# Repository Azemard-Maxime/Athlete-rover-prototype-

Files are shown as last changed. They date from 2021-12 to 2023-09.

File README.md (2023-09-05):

# Athlete-rover-prototype-
Projet Arduino PeiP2: 
Lunar rover prototype

Création d'un robot capable de se déplacer et de grimper sur des obstacles. Inspiré par le rover lunaire Athlete. (L'objectif étant de simuler son comportement)

Creation of a robot which can move and climb on obstacles. Idea inspired by lunar rover Ahtlete.(Objective: simulation of the movement of a rover on uneven reliefs)

168147main_image_feature_748_ys_full

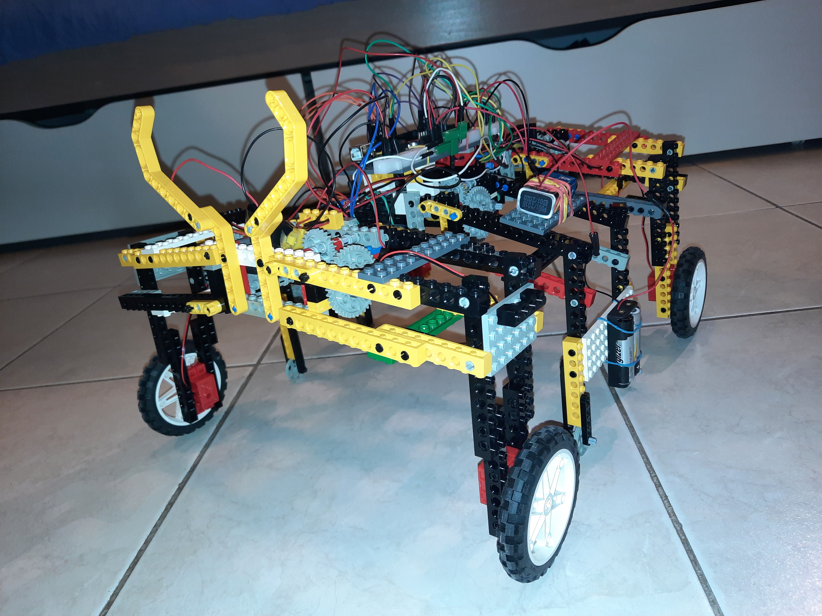
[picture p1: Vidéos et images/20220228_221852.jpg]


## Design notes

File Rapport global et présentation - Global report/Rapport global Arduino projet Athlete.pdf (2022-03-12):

# Athlete-rover-prototype-

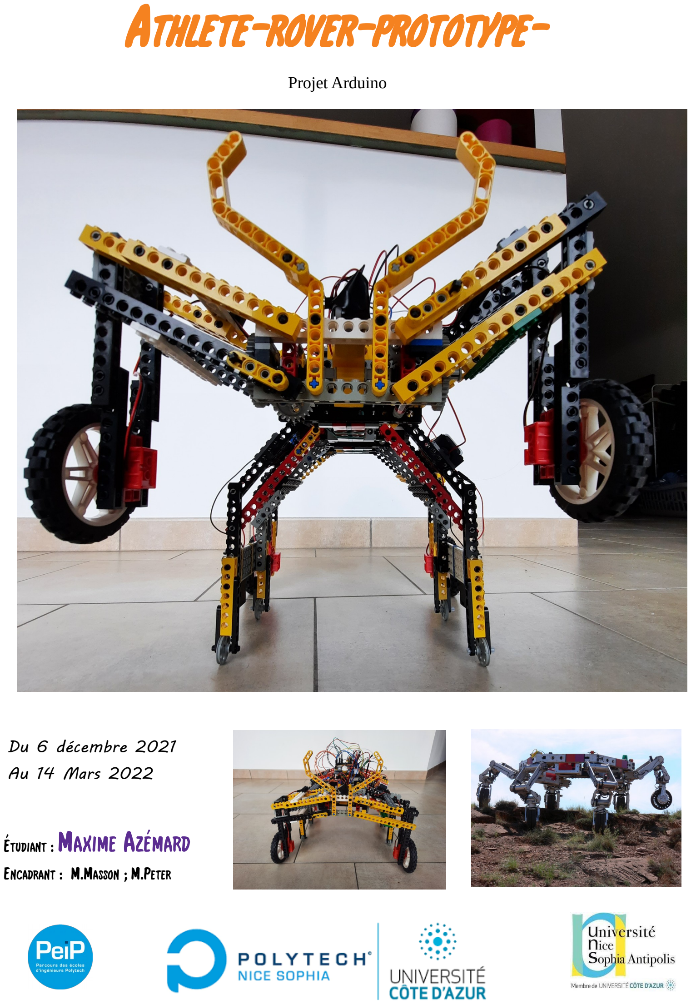
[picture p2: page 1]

Projet Arduino

# Étudiant : Maxime Azémard

### Encadrant : M.Masson ; M.Peter

### Du 6 décembre 2021 Au 14 Mars 2022

### Remerciements

L’équipe de création du prototype de rover Athlete remercie particulièrement M.Masson et son équipe pour leur implication, leur suivi et leurs conseils avisés. Nous remercions M.Juan pour la prise en charge efficace de l’impression des pièces nécessaires, et nous remercions l’université Côte d’Azur et l’école polytechnique universitaire de l’académie de Nice pour avoir permis l’accès au matériel et au outils de conception utiles à la réussite du projet.

Sommaire

Introduction Objectif réalisation
Contraintes (cahier des charges – planning initial – final Le matériel

Partie 1 : Le prototype initial
Partie 2 : Un robot plus modeste
Partie 3 : Un robot Athlète
Conclusion – Perspectives d’évolutions Bibliographie

## Projet Athlète : « A l’assaut du relief »

Depuis quelques années, la conquête spatiale s’accélère considérablement. Les agences spatiales du monde entier (la NASA, l’ESA, Roscosmos, ect) se préparent à un retour imminent et prolongé sur l’astre lunaire, et les envois de sondes et rovers à but scientifique s’intensifient avec l’objectif de voir, dans un futur proche, le premier être humain sur Mars.
Ces rovers, à l’image de Curiosity, parcourent des kilomètres afin d’étudier les minéraux et les sols extraterrestres. Ils se retrouvent ainsi face à un défi de grande envergure : le relief. Celui ci se dresse tel un obstacle destiné à freiner leurs progressions. Pour les ingénieurs actuels, la création d’un robot capable de se déplacer aisément sur ce relief représente l’un des principaux enjeux de la conquête spatiale à venir.
C’est dans l’objectif de répondre à cette difficulté que la NASA et le Jet Propulsion Laboratory développent en ce moment même le rover Athlete (All-Terrain Hex-Limbed Extra-Terrestrial Explorer ). Ce rover est composé de 6 trains de roues articulés qui s’adaptent au niveau du sol afin que la plateforme du robot reste stable de façon permanente. A l’avenir, l’agence spatiale américaine prévoit de l’envoyer sur la Lune à des fins de transports de marchandises, ou de modules d’habitats pour les futurs arrivants.
L’objectif de ce projet est de comprendre, par l’intermédiaire de la création d’un robot articulé et motorisé, comment se comporte le rover Athlete et de quelle façon il capable de franchir une différence de relief.
Au cours de ce rapport, après vous avoir présentez le premier prototype initial du robot, nous discuterons de la version simplifiée créée en milieu de projet avant de nous attacher à la présentation du robot finalisé à l’effigie de Athlete.

### Sommaire

Introduction | p.2
Cahier des charges – objectif de réalisations et contraintes | p.3
Le matériel | p.3
Partie 1 : Le prototype initial | p.4
Partie 2 : Un robot plus modeste | p.6
Partie 3 : Un robot Athlète | p.7
Conclusion – Perspectives d’évolutions | p.9
Bibliographie | p.10

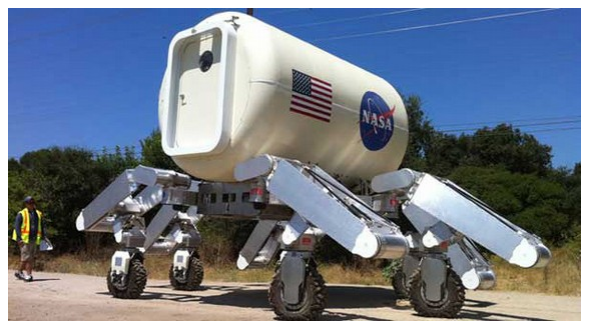
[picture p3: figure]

Photographie deAthlete
transportant un module
d’habitation

### Cahier des charges

Objectif : création d’un robot capable de réaliser la montée et la descente d’un obstacle afin de simuler le comportement d’Athlete lors de son déplacement sur des reliefs escarpés. Le robot doit être manipulé à distance avec un système de télécommande.

Projet de réalisation : Créer un robot composé de 3 trains de roues qui s’élèvent et s’abaissent successivement afin de se hisser ou descendre d’un obstacle.

Contraintes de réalisation :

- le robot doit être équipé de 3 paires de roues au minimum pour la gestion du centre de gravité.
- les trains avants et arrières doivent posséder des roues motrices et des pneus adhérents au sol afin de pouvoir pousser ou tracter le robot lors des phases de montée et de descente.
- le robot doit pouvoir communiquer à distance avec une télécommande. Un système de transfert de données est donc nécessaire (Bluetooth, …)
- chaque train doit être capable de fonctionner indépendamment des autres. Mais aussi tous ensemble.
- Le poids et les matériaux utilisés doivent être pris en compte afin de permettre une meilleure gestion du centre de gravité.
- chaque train de roues doit être capable de s’abaisser et se relever. Son articulation nécessite une motorisation
- Le robot nécessite d’avoir avec lui une source d’énergie : pile,etc
- nécessité d’une quantité importante de moteurs et roues
- délais : 8 semaines

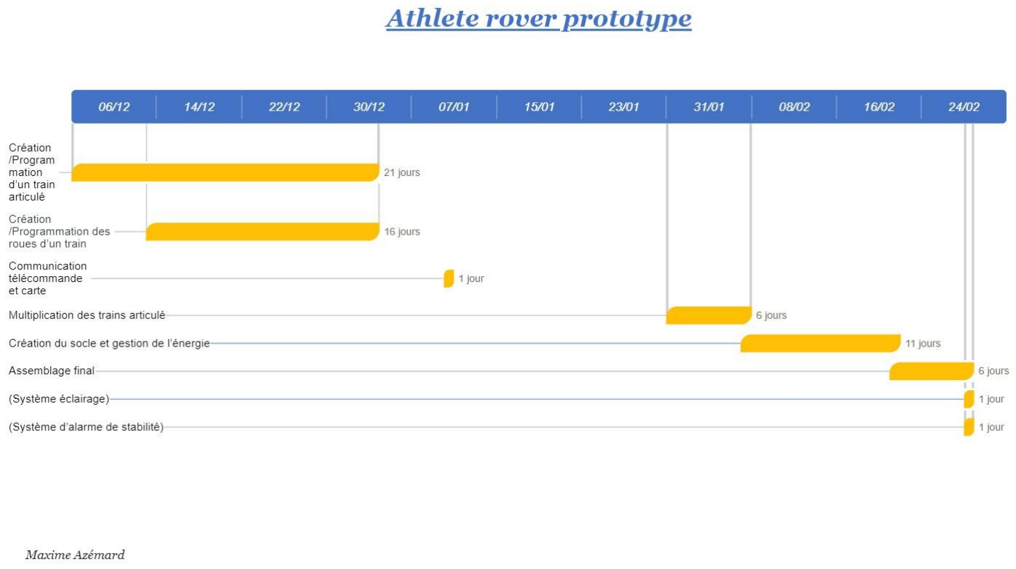
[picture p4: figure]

### Détails du matériels

Pour débuter, il est nécessaire de bien comprendre le matériel utilisé tout au long de ce projet. En voici quelques descriptions :

Planning initial du projet

- La carte Arduino UNO : Une carte programmable standard équipée d’un microcontroleur. Elle possède 14 entrées numériques dont 6 entrées « Pulse Width modulation » et 5 broches analogiques.
- La carte Arduino MEGA : Une carte programmable plus avancée que le modèle UNO. Utilisée pour des projet de plus grande envergure, elle possède 54 entrées/sorties dont 16 analogiques et 14 de type PWM.
- Les ponts en H : Un circuit permettant de contrôler deux moteurs à courant continu, ou un moteur pas à pas. Les ports ENA et ENB permettent de moduler la tension ce qui équivaut à moduler la vitesse des moteurs. Les entrées IN1, IN2, IN3 et IN4 permettent d’indiquer le sens de rotation des moteurs.
- Le module hc-05 : Un module qui fonctionne en Bluetooth et qui permet la communication entre la carte et un appareil externe. Fonctionne de pair avec l’application « Bluetooth electronic »
- Les moteurs Lego Geek : Des moteurs Lego à courant continu compatible avec Arduino
- Les moteurs « jaunes » : de simples moteurs à courant continu
- Les servomoteurs : des moteurs capables de prendre une position spécifique comprise dans un angle allant de 0° à 180°.

Partie 1 : Le prototype initial

L’objectif de cette première partie du projet est d’obtenir un premier prototype fonctionnel du robot. Il faut donc commencer par se poser certaines questions : Comment créer la structure de l’appareil ? Comment articuler les trains de roues et y insérer des moteurs ? Quels matériels utiliser ?

### I- La création du premier robot

De par la facilité d’utilisation, la brique Lego s’est avéré être plutôt adapté à ce projet. Après la création rapide d’un modèle de train pouvant être utilisé, la
structure du robot a pu être lancée. Celle-ci se décompose en 4
parties. Les trains avants et arrières qui se déploient vers
l’avant et qui sont composés chacun d’un moteur à courant continu compatible avec la structure Lego, qui contrôle l’articulation, et d’un autre moteur Lego qui permet la
motorisation des roues. Ce mouvement est possible grâce aux
vis sans fin qui maintiennent toutes la structure.

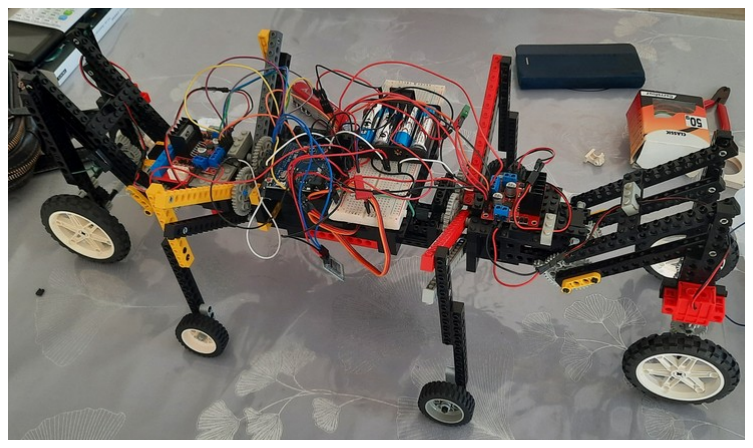
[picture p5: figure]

Les deux trains centraux sont équipés de servomoteurs. Par l’intermédiaire d’une pièce de jonction, ceux ci sont rattachés à des axes Legos qui sont eux-même reliés à des articulations à roulettes. Ici on remarque l’absence des vis sans fin.
L’électronique du robot nécessite l’utilisation de plusieurs modules. En ce début de projet, le choix de l’utilisation de la carte Arduino UNO a été fait afin de faire la liaison entre les commandes informatiques et l’électronique du robot. Ensuite, il a fallu s’équiper de 2 ponts en H qui servent d’intermédiaire entre la carte et les moteurs. Enfin un module de Bluetooth a été rajouté. Tous ces composants ont été ajoutés sur la structure mécanique Lego du robot et les branchements ont pu être effectués. Une platine d’essai s’est avérée indispensable pour permettre la bonne connexion de tous les modules. S’en est suivi l’introduction d’un bloc d’alimentation de 6V par piles et d’un interrupteur.
Enfin il a fallu programmer le prototype. Pour cela, un travail préparatoire a été nécessaire afin de créer des petits sous-programmes destinés aux tests des différents modules. A savoir, les

### Partie 1 : Le prototype initial

servomoteurs, les moteurs, et la connexion au module Bluetooth. Pour suivre, la télécommande a pu être créée et le premier programme écrit. L’idée ici est de permettre à l’utilisateur de manipuler tous les trains articulés ainsi que le déplacement de l’engin.

### II- Les problèmes rencontrés

Lors de la création de ce premier prototype de machine, plusieurs problèmes mécaniques se sont posés.
Premièrement, la question de l’insertion des moteurs Lego dans les parties avant et arrière ont été un problème. Pour le résoudre et obtenir la structure la moins coûteuse en pièces, il a fallu recréer et modifier plusieurs fois ces zones. Le but est ainsi d’avoir les trains les moins lourds possible.
Un autre problème de mécanique qui est apparu est la faible puissance des moteurs. Ils n’étaient pas capable de relever l’articulation. Pour cela l’utilisation d’engrenages est devenu indispensable. En effet il est possible grâce à eux de décupler la puissance exercé mais cela réduit considérablement la vitesse.
Pour suivre, il était devenu nécessaire de solidariser la structure. En effet les forces d’écartements qui s’exerçaient sur le robot fragilisaient énormément la structure de celui ci. Ce problème n’a pas pu être complètement résolu mais l’accrochage d’une grande barre Lego traversant tout l’appareil a permis de réduire considérablement cet effet de destruction.
On remarque un autre problème qui vient de la platine d’essai. On remarque qu’elle alourdi le robot alors qu’une grosse partie de la plaque n’est pas utilisée. Ce problème persistera une grande partie du projet. Il est aussi très délicat de trouver de la place pour insérer cette platine dans la structure.
Concernant la programmation, il a fallu s’occuper de certaines difficultés. Notamment liées aux servomoteurs qui ne fonctionnaient pas correctement lorsque l’on ne récupérait pas la valeur du module Bluetooth à chaque instant. Cela diffère de l’idée initiale qui consistait à étudier la valeur du module uniquement lorsque il y avait une modification de cette valeur.
On remarque un important problème sur ce prototype. La perte énorme de tension de 2 à 3V entre la sortie de l’alimentation et l’arrivée aux moteurs. Un problème probablement dû aux pertes dans le circuit et à la répartition de la tension entre tous les modules, ce qui a eu pour conséquence particulière la déconnexion du module Bluetooth. Ce problème est réduit par l’utilisation d’une alimentation filaire de 7,5V qui complète l’alimentation à piles.

### III- Bilan du prototype

Le premier test du robot ne s’est pas avéré concluant. En effet il ne rempli pas les critères indiqués dans son cahier des charges. Lors de la phase de test le robot n’est pas capable de maintenir son propre poids. La force exercée sur les servomoteurs étant trop importantes lorsque le train avant se soulève, le robot s’écrase sur lui même.
Nous sommes alors à la moitié du délai imposé pour la réalisation de ce projet. Il faut donc réadapter le planning afin de pouvoir obtenir un engin opérationnel

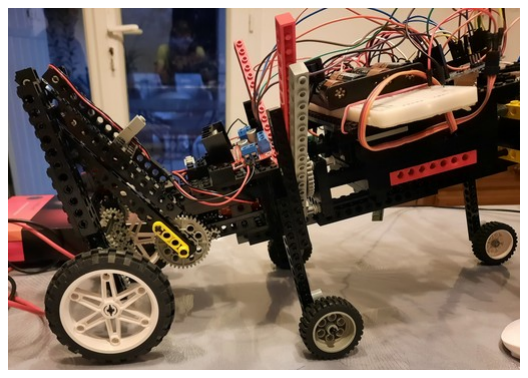
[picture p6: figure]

Photographie traduisant l’écrasement du robot lorsque le train avant monte

Partie 2 : Un robot plus modeste

A présent, il s’agit d’obtenir une deuxième version du robot qui réponde complètement à la contrainte initiale de création : monter sur un obstacle. Le premier prototype a permis de déduire que l’utilisation de servomoteurs était superflu et que les vis sans fin sont indispensables à la réussite de l’opération.

### I- Création d’une version simplifiée du prototype initial

Afin d’obtenir une structure plus légère. Il a été nécessaire de se dispenser des deux trains de roues centraux. Il ne reste alors que les trains avant et arrière. L’un des moteurs responsable de la motorisation arrière a été basculé sur la partie avant. Il y a donc
maintenant un moteur par roue avant. La principale modification
de la structure provient des trains articulés. Ils ne se décomposent
plus en deux parties mais en seulement une. Les roues retirées sur les trains centraux ont été rajoutés sur les trains avant et arrière mais positionnées en début d’articulation. L’idée est que lorsque les roues avants se soulèvent, elles seront remplacées par ces roues plus petites qui viennent prendre appui avec le sol. Grâce à un ingénieux système d’axe et d’engrenages, l’énergie du moteur de
la roue avant est retransmise à la roue de remplacement qui
devient alors motorisé. La structure a aussi été renforcée par des

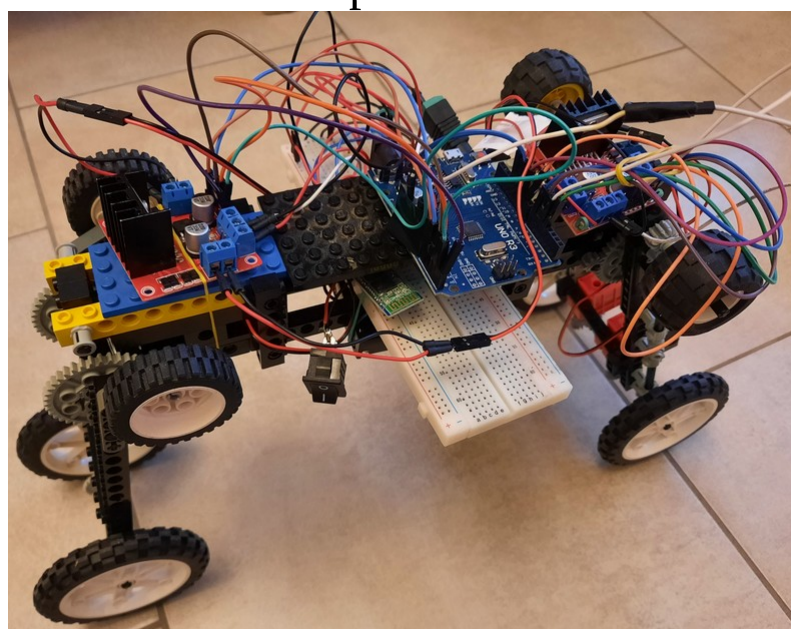
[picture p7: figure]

entretoises qui solidarisent le socle du robot afin d’éviter une destruction des pièces.
L’électronique de ce robot a ensuite été branchée sur la carte Arduino UNO puis accrochée au niveau de la partie centrale. La platine d’essai est insérée orthogonalement aux axes qui maintiennent l’agencement de l’appareil et on dispose dessus le module Bluetooth. Le bloc d’alimentation est accroché avec des élastiques sous le robot mais il n’est pas utilisé dans l’immédiat. Les ponts en H et la carte sont simplement fixés sur le socle central. L’alimentation filaire remplace les piles en attendant une évolution permettant de s’en dispenser en conservant une tension suffisante.
Le code enregistré pour l’utilisation de ce robot est une version simplifiée du premier programme destiné au prototype initial. On remarque l’absence du code rattaché aux servomoteurs puisqu’ils ont été retirés. La télécommande a aussi dû être légèrement réadapté pour l’utilisation de l’appareil.

### II- Les problèmes rencontrés

L’une des difficultés lors de cette création a été de placer la platine. Elle est trop longue pour le robot. Il a donc fallu la mettre orthogonalement à la structure ce qui n’est pas très esthétique, et pratique pour les déplacements.
Initialement, l’un des moteurs était resté sur le train arrière pour motoriser la roue et l’autre était à l’avant. Mais les engrenages avaient tendances à se déloger dans cette configuration et les moteurs forçaient plus que nécessaire. Cela a été résolu en mettant les deux moteurs à l’avant. Mais en contrepartie nous perdons la motorisation du train arrière.
Une fois encore la structure mécanique du robot a dû être modifiée plusieurs fois. Il a fallu retirer un maximum de pièces afin d’alléger l’ensemble, d’autant plus que la platine est très lourde. Le système d’engrenages en sortie des moteurs reste indispensable.
La perte de tension est toujours présente sur cette version du robot. Un des difficultés est de fournir suffisamment d’énergie aux moteurs pour qu’ils puissent relever les articulations. Pour cela il est toujours nécessaire d’utiliser l’alimentation filaire.

### Partie 2 : Un robot plus modeste

### III- Bilan de test

Finalement, cette version du robot s’éloigne du comportement attendu dans le projet de réalisation, mais les tests s’avèrent concluants ! Le robot est capable, par inversion du sens des trains de roues, de monter un obstacle de 15cm de haut ainsi que de
le redescendre. La création de cette version remaniée du robot aura
nécessité 1 séance de cours en plus du travail personnel effectué.

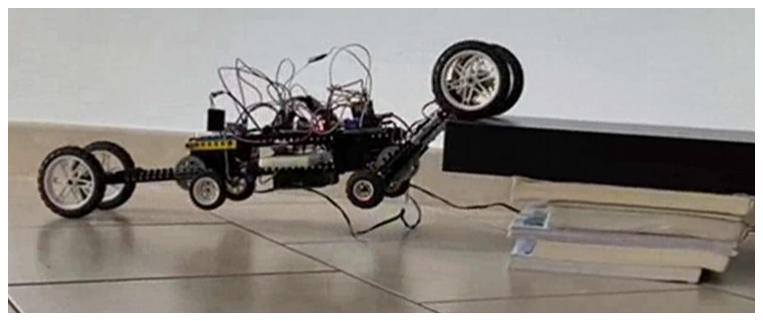
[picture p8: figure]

Cette version du robot garantie la réussite du projet dans les délais attendus. Mais on remarque qu’il ne se comporte pas comme le rover Athlete et il va nous falloir faire encore évoluer le projet afin d’obtenir le prototype attendu.

Partie 3 : Un robot Athlète

Dans cette dernière partie, l’objectif est d’obtenir un robot fonctionnel le plus proche du comportement de Athlete. Il faut donc résoudre les problème de la première version du robot.

### I- Le robot final

En ce qui concerne la structure, le robot ré-adopte l’utilisation d’un train
central. Il se décompose en 3 parties Lego symétriques. Les parties aux extrémités possèdent des roues motorisées par les moteurs Legos. Et le train central possède deux paires de roulettes non motorisées. Chaque partie possède
un moteur jaune classique afin d’articuler le mouvement de montée et de
descente des trains. Chaque moteurs est relié à une vis sans fin qui va pouvoir

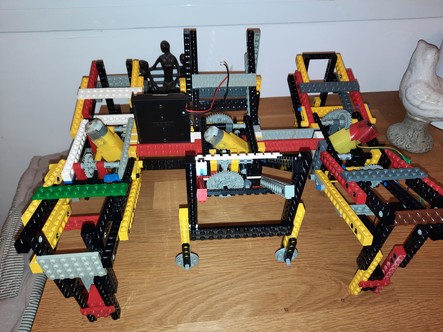
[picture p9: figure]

retenir le poids de l’ensemble ce qui empêche tout problème de chute. Les 3 parties sont rattachées entres elles par des plaques verticales.
Pour suivre, les différents modules ont été associés à la structure mécanique. Les ponts en H et le module Bluetooth sont rattachés aux jonctions verticales. Une carte de type MEGA est maintenant attachée avec des élastiques sur une plaque Lego située au centre de l’appareil. La platine d’essai disparaît pour ne laisser que 4 colonnes de la platine dont deux sont associées à des alimentations et les autres à la masse. Cette alimentation est double. La carte et le module Bluetooth sont alimentées par les piles de 6V et les moteurs sont alimentés par une pile de 9V.
Le programme associé au robot finalisé est une complexification du code de la 2e version.
Chaque caractère envoyé est étudié. Si on trouve une correspondance avec une opération, alors le code impose d’afficher dans le moniteur un message, et d’effectuer cette opération. Une nouvelle

### Partie 3 : Un robot Athlete

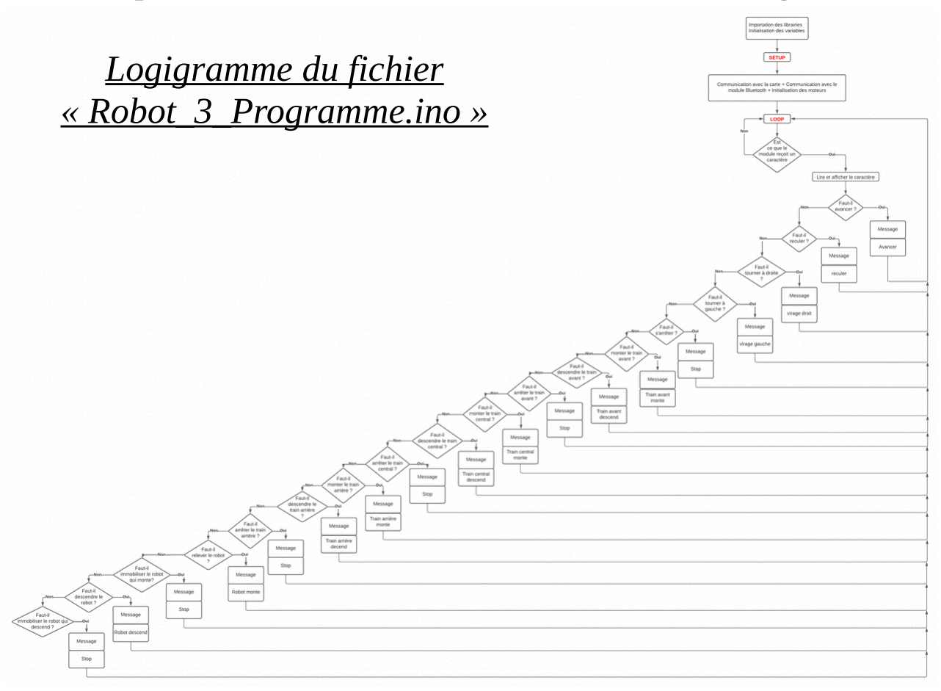
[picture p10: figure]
Logigramme du fichier « Robot_3_Programme.ino »
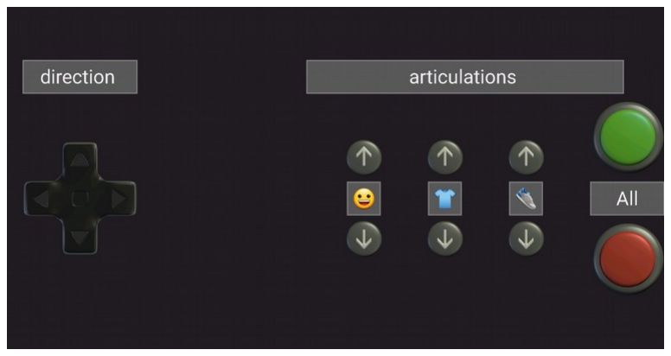
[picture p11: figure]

Télécommande du robot sur
Bluetooth electronic télécommande a été réalisée. Elle est composée de 8 boutons de mouvements des articulations et un bouton de contrôle des déplacements, notamment les virages.

### II- De multiples problèmes

Pour commencer, on remarque que la structure est très lourde de part la taille des différents trains. Pour pouvoir avoir assez de puissance pour soulever cette structure, il a été nécessaire de multiplier par 120 la puissance des moteurs et de les alimenter en 9V indépendamment des autres modules. Cette multiplication a été possible par l’utilisation d’engrenages de 8 dents, 24 dents et 40 dents. Cela justifie aussi l’utilisation des deux types d’alimentations et permet de résoudre la perte de tension. De plus cela permet l’abandon définitif de la connexion filaire.
Ici encore, la jonction entre les moteurs jaunes et les axes Legos était impossible. Une pièce spécifique à donc été imprimée afin de résoudre ce problème.

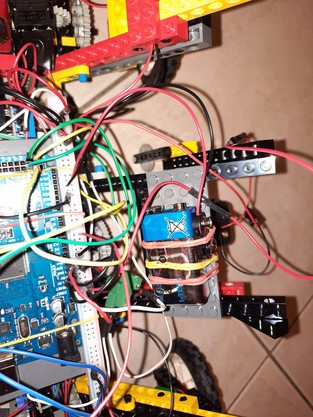
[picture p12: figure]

Beaucoup de forces s’appliquent sur le robot. Cela provoque la destruction de la structure. Pour éviter cela, plusieurs pièces font office d’entretoises. Notamment au niveau des sorties moteurs ou lorsque les pièces bougent, l’engrenage relié à la vis sans fin se déplace et paralyse le train concerné.
Le nombre insuffisent de ports sur la carte Arduino UNO était aussi un élément à résoudre. Pour cela cette carte a été abandonnée au profil du modèle MEGA.
Afin de distinguer tous les différents modules, il a fallu procéder à un trie et une codification particulière des câbles colorés. Cette rigueur était importante puisque trois alimentations différentes se répartissent dans le robot. Les piles apportent 6V, la pile de lithium produit 9V et la carte Arduino permet d’obtenir une 3e
alimentation de 5V. Appliquer une mauvaise tension sur un module pourrait le détruire.
Afin de connecter tous les modules nécessitant du 5V au seul port rattaché à cet effet, l’utilisation de raccord emboîtables c’est révélée la mieux adaptée. En effet sur les colonnes d’alimentation issues de la platine, nous avons 4 zones spécifiques. Les deux zones indicées par le symbole « + » servent d’alimentation. Les deux zones indicées « - » servent de masse. Il aurait été possible d’utiliser l’une de ces colonnes de masse comme une colonne d’alimentation de 5V mais le risque était la présence du signe « - » sur cette endroit. Nous aurions pu confondre cette zone durant le projet et ainsi détruire un composant en pensant le rattacher à la masse. Le choix à donc été d’opter pour des raccords.
Un autre défi à relever était le choix des roues. Trouver le meilleur compromis entre des roues qui adhèrent suffisamment lors des phases de traction et en même temps des roues capable d’avoir un frottement minimal au sol lors de la montée des trains n’était pas chose aisée. Finalement nous avons choisi des roues fines à pneus caoutchoucs.
Ensuite, un souci venant des câbles est descellé. Beaucoup se détachent avec les forces de tractions notamment un câble vert à l’origine du contrôle des roues droites du robots. Pour résoudre cela, plusieurs câbles ont été soudés ou accrochés avec du ruban adhésif.
Pour finir un problème lié à la programmation a du être résolu. Lors des virages le robot tournait sur lui-même ce qui appliquait énormément de forces sur la structure et détachait plusieurs pièces régulièrement. Cela a été modifié afin que le robot tourne en effectuant des virages. La réduction de sa vitesse globale a permis aussi de réduire les chocs subit par l’ensemble lors de l’arrêt.

Page 8

### III- Bilan du robot Athlete

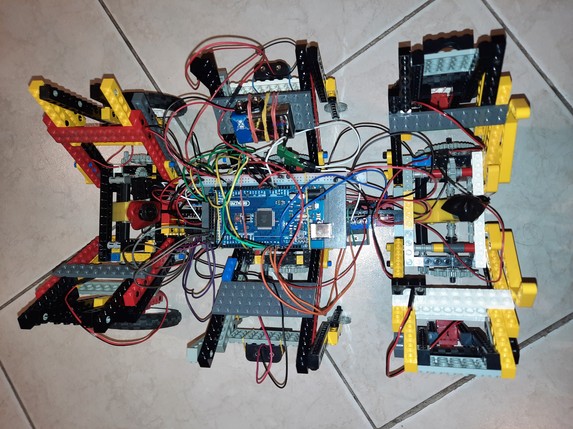
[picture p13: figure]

Le test final du robot Athlete s’avère être une réussite. En effet le robot est capable de se redresser sur lui même et de relever successivement ses différents trains de roues afin de monter sur un socle d’environ 20cm de hauteur. Il peut ensuite en redescendre et se rabaisser pour continuer son chemin.

Conclusion, comparaison et perspectives d’évolution

Finalement, après 9 semaines de projet, le robot est fonctionnel. Sa compétence de déplacement sur des obstacles de différents niveau le rapproche considérablement du rover Athlete ce qui était attendu initialement. Ce robot est capable lors de son test de s’avancer jusqu’à l’obstacle. Il se redresse pour être le plus haut possible puis son train avant se relève. Par poussée des roues arrières il s’avance et les roues avants prennent appui sur le socle. Puis le train central effectue le même mouvement. Enfin le train arrière peut se relever puisque tout le poids se situe sur l’avant du robot. Le robot Athlete atteint donc l’objectif de réalisation. Par le mouvement inverse il peut aussi en redescendre. Puis il continue sa route en avançant, reculant et effectuant des virages, l’ensemble selon le choix de l’utilisateur.
De part certaines difficultés rencontrés, le projet initial a été modifié. On remarque que l’objectif d’utiliser des servomoteurs n’a pas pu être atteint pour des raisons de puissances et d’équilibre. Cela a été remplacé par des moteurs classiques. Le mouvement des trains avant et arrière à aussi été modifié par rapport à l’idée initiale puisque les trains s’ouvrent à présent sur les côtés. Ces changements ont impacté la répartition des taches dans le planning.

Il est important de remarquer que certaines difficultés persistent. En effet nous atteignons la limite des Legos. La structure se déforme sous les forces qui s’exercent et les engrenages subissent énormément de pression ce qui pourrait détruire des dents. De plus la perte de tension qui est dû aux rallonges et autres liaisons nécessite deux alimentations spécifiques pour être compensé ce qui est

Séances | 13 Déc | 3 Janv | 10 Janv | 31 Janv | 7 Févr | 21 Févr | 28 Févr
Création structure robot 1
électronique robot 1
Programme de test
Communication Bluetooth
Programmation robot 1
Gestion de l’alimentation robot 1 Structure robot 2
électronique robot 2
Programmation robot 2
Structure robot 3
Électronique robot 3
Programmation robot 3
Gestion de l’alimentation robot 3

6 Déc

Conclusion, comparaison et perspectives d’évolution

Planning réalisé

Image représentant
les différents
engrenages Legos

Représentation numérique
3D de la pièce de jonction | Photographie verticale du
| robot présentant la carte et les
| colonnes d’alimentations

Image d’une vis sans
fin Lego très coûteux en énergie. Enfin les roues actuelles ne sont pas les plus adaptés puisqu’elles frottent contre le sol lors du mouvement (adhérence).
Avec 9 séances de plus sur ce projet il serait possible de modifier le type de roues afin de réduire les frottements latéraux lors des phases de montée et descente. Ensuite la structure pourrait être renforcée. En ce qui concerne les évolutions possibles, nous pourrions envisager l’automatisation du robot avec un module de son qui distingue la distance avec les obstacles. Des diodes lumineuses et des capteurs sur les trains pourraient aussi être rajoutées. Lorsque l’angle limite d’un train est atteint, une diode s’allume. Enfin un capteur d’horizontalité pourrait être rajoutée afin d’indiquer à l’utilisateur lorsque le robot bascule trop en avant ou en arrière. Dans le but de corriger la trajectoire.
Pour conclure, ce projet a pu apporter de multiples connaissances mécaniques et électroniques. Nous avons appris à évoluer face à l’échec, et s’adapter aux différentes situations nouvelles en restant autonome. Malgré tout, l’expérience montre que certains éléments auraient pu être abordés différemment. La connaissance des limites des servomoteurs auraient permis de comprendre qu’ils ne seraient pas adaptés ce qui aurait éviter la perte de temps occasionnée par la création du premier prototype non fonctionnel. Les Legos n’étaient pas non plus les mieux adaptés puisqu’ils sont lourds. Enfin le problème de l’énergie aurait pu être solutionné dans l’immédiat.
Le temps gagné sur ces éléments aurait pu permettre d’envisager de faire plus évoluer les compétences du robot, et d’envisager une automatisation.

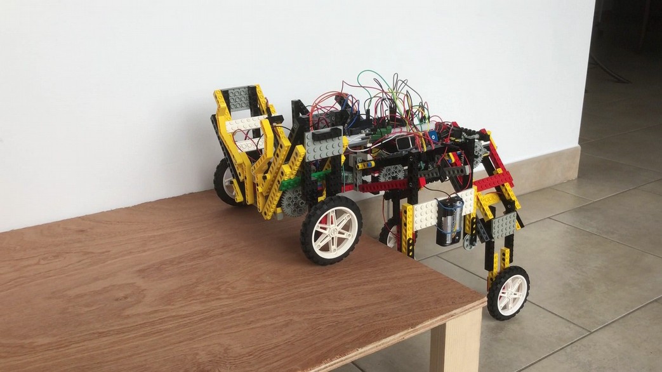
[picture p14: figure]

Bibliographie

https://www.locoduino.org/spip.php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
https://www.youtube.com/watch?v=MwHHErfX9hI

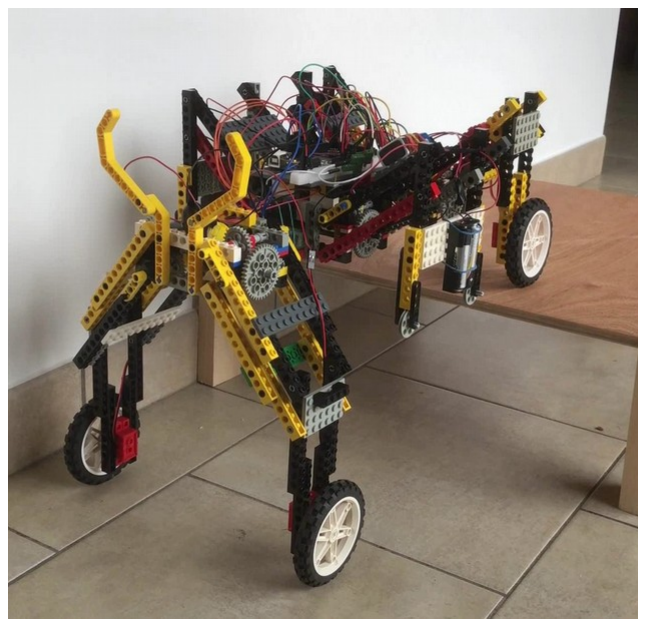
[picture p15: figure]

Lego mindstorms - (https://www.youtube.com/watch?v=MwHHErfX9hI) Baum (Auteur) (https://www.fnac.com/ia1669648/Baum) - Les créations (https://www.youtube.com/watch?v=MwHHErfX9hI) robotiques de Dave Baum-Paru en novembre 2000-Livre-jeu (Livre CD-ROM) (https://www.fnac.com/ia1669648/Baum)

Le robot Athlete en phase
de montée

Le robot Athlete en
phase de descente

Bibliographie

https://www.locoduino.org/spip.php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 (https://en.wikipedia.org/wiki/ATHLETE)nement.htm https://en.wikipedia.org/wiki/ATHLETE
https://www.youtube.com/watch?v=Mw (https://www.fnac.com/ia1669648/Baum)HHErfX9hI
Lego mindstorms - Baum (Auteur) (https://www.fnac.com/ia1669648/Baum)
- Les créations robotiques de Dave Baum-Paru en novembre 2000-Livre-jeu (Livre CD-ROM)

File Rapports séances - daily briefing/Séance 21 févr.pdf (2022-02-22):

Azémard Maxime | PeiP2 Gp1

## Rapport séance 21 février 2022

### Travail personnel

A présent, nous avons la version simplifiée du robot d’opérationnelle. L’objectif premier des vacances est de finaliser cette version afin de le filmer lors du passage d’un obstacle.
Pour commencer j’ai chargé tous les éléments électroniques sur le robot. Une difficultée est le manque de place sur cette version très fine. Ainsi la carte et les ponts en H ont été placé sur la partie supérieure du robot. La platine d’essai a été inséré dans la structure mais malheureusement elle se retrouve perpendiculaire à la longueur de l’appareil. Enfin les piles ont été accrochées sous le robot par le biais d’élastique. Lors de l’essai on relève que l’engin étant très lourd, il a des difficultés lors du mouvement. Le même problème que la version précédente est relevé. Une forte perte de tension qui a pour conséquence de rendre les moteurs trop faibles. J’ai donc branché d’une part la carte et le module Bluetooth sur l’alimentation de 6V, et d’autre part les moteurs sur une alimentation extérieure de 7,5V. Le résultat est positif. Le robot traverse sans problème l’obstacle positionné sur son chemin. On note qu’il n’est pas aisément capable de tourner à droite ou à gauche. Les forces qui sont exercées sur lui sont trop importante dans cette configuration.

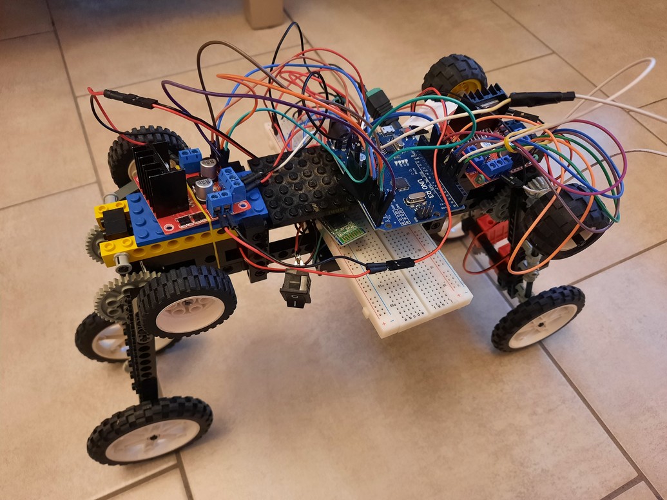
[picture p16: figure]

Pour suivre, je vais chercher à résoudre les problèmes de la version complexe du robot afin de proposer un appareil fonctionnel.
Pour débuter, l’idée est de remplacer les servomoteurs par des moteurs classiques équipés de vis sans fin destinées à retenir le poids du robot. Ne possédant que 4 moteurs Arduino compatible avec des Legos, il va être indispensable d’utiliser des moteurs à courant continu classiques. Il faut donc modéliser et imprimer à l’imprimante 3D une pièce capable de faire la jonction entre une sortie moteur et un axe Lego. Cette pièce aura été imprimée une première fois mais certains côtés, trop fin, ne se sont pas bien imprimés et la pièce était défectueuse, de part sa fragilité. Pour suivre j’ai modifié certaines dimensions et réimprimé des pièces (6 exemplaires) avec différentes longueurs d’encoche pour le coté moteur (à savoir, 3mm, 4mm et 5mm). Les pièces de 4 et 5 mm conviennent. Les pièces avec une encoche de 3mm de longueur étaient trop petites et ont été creusées avec une perceuse afin d’être utilisable.

Photographie du robot
en version simplifié

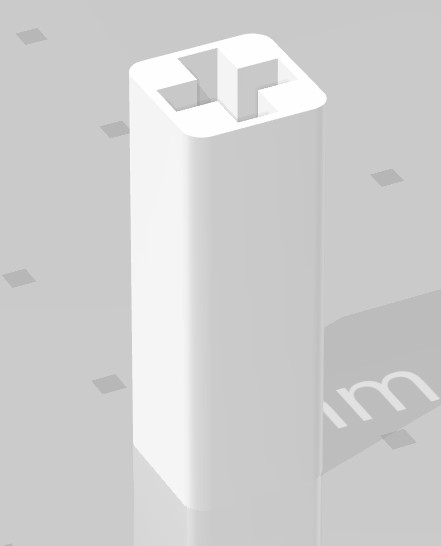
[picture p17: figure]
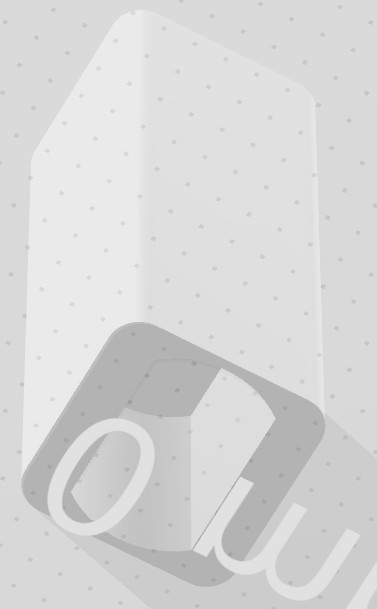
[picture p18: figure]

Ensuite, il faut recréer la structure du futur robot. Avec des Legos, j’ai recréé 3 trains de roues mais sur un modèle complètement différent que la première version. En effet les trains arrières et avant ne se déploieront plus vers l’avant et l’arrière mais sur les côtés, sur le même modèle que la partie centrale. Nous plaçons un moteur Lego sur chaque extrémité du robot (récupérés sur la version 2, en partie démontée pour ses pièces). Ils serviront aux déplacements. Chaque train est équipé d’un moteur à courant continu qui sert aux mouvements de l’articulation. L’utilisation d’engrenages à 8 et 40 dents permet d’augmenter la force exercée lors de la montée des trains. Une difficulté était l’optimisation de la place sur le robot afin d’obtenir une articulation puissante mais la plus légère possible. Ce problème a été résolu en modifiant 3 fois la structure autour du moteur. Sur le train central, on accroche de part et d’autre des blocs de deux piles (dont temporairement un de 4 emplacements de piles). Branchées en série, elles fourniront 6V. L’idée est d’obtenir les 6V d’une alimentation en répartissant le poids des piles sur toute la structure.

Image 3D de la
pièce de jonction
en vue de dessus
(à gauche) et en
vue de dessous (à
droite)

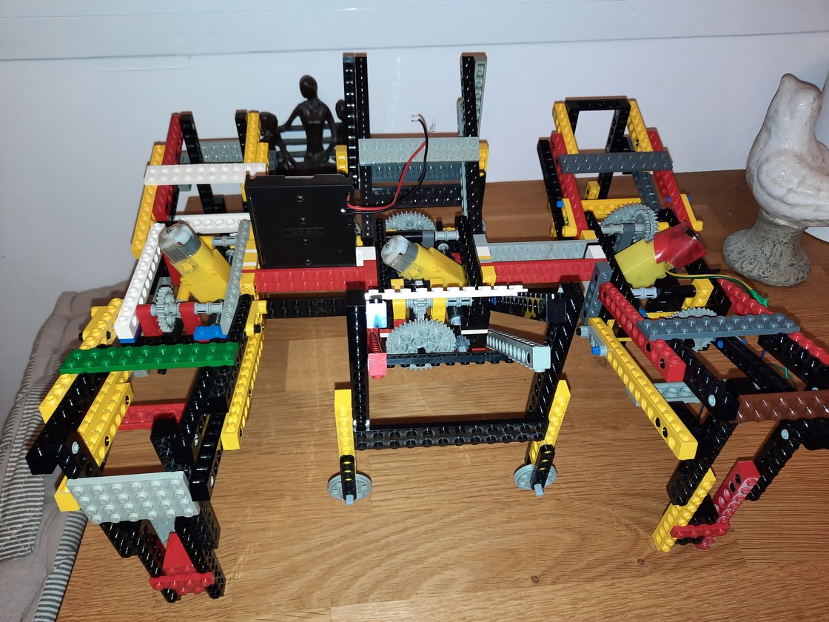
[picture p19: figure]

Photographie de la
structure Lego de la
dernière version du
robot

A présent les articulations Legos ont été créées. Les liaisons entre les 3 trains se font grâce à des plaques verticales sur lesquelles il sera possible d’accrocher les différents composants électroniques. Aisément détachable, ces structures pourront être retirées afin de faciliter l’accès aux moteurs lors du câblage. Nous y attachons deux ponts en H sur l’un, et un pont en H et le module Bluetooth sur l’autre avec des élastiques.

Pour suivre, il faut brancher l’électronique du robot. De part le nombre insuffisant de ports sur la carte Arduino UNO, je me suis dirigé vers l’utilisation d’une carte Arduino MEGA. Un autre problème est le manque de port de 5V sur la carte. Cela rend indispensable l’utilisation d’une platine d’essai qui est, de toute évidence, trop lourde. Le problème à donc été solutionné en détachant une barre de 2x50 encoches de la platine et composée de 3 parties dont deux pour des alimentations et une pour la masse. Nous utilisons la première zone d’alimentation pour le 6V des piles et la dernière zone d’alimentation pour le 7,5V de la prise. Ensuite, j’ai accroché ces deux éléments (carte et plaque) sur le dessus du train central avec des élastiques. En ce qui concerne le câblage, j’ai procédé à un tri des couleurs afin de les associer à chaque éléments du montages. Ainsi les câbles gris, violets, jaunes, verts et oranges sont les câbles rattachés aux différents moteurs des ponts en H. On remarque que l’on ne branche que 5 moteurs sur les 7. En effet les moteurs de déplacements, situés aux extrémités avants et arrières fonctionneront par pair. Une paire n’utilise qu’une sortie d’un pont en H. Ensuite, les câbles bleues correspondent aux entrées RX et TX du module Bluetooth. Les câbles rouges récupèrent en fonction de leur position, soit l’alimentation de 6V des piles, soit l’alimentation de 7,5V de la prise. Les câbles blancs rejoignent le 5V de la carte et les câbles noirs correspondent à la masse. Les ports de la carte et la taille des câbles sont choisis de façon à se que la distance entre le composant et la carte soit la plus faible. L’idée ici est d’éviter le chevauchement des fils. On remarque que le 5V n’étant pas fournit sur la platine, j’ai utilisé des raccords qui s’emboîtent afin de fournir le 5V à tous les éléments qui en avait besoin.

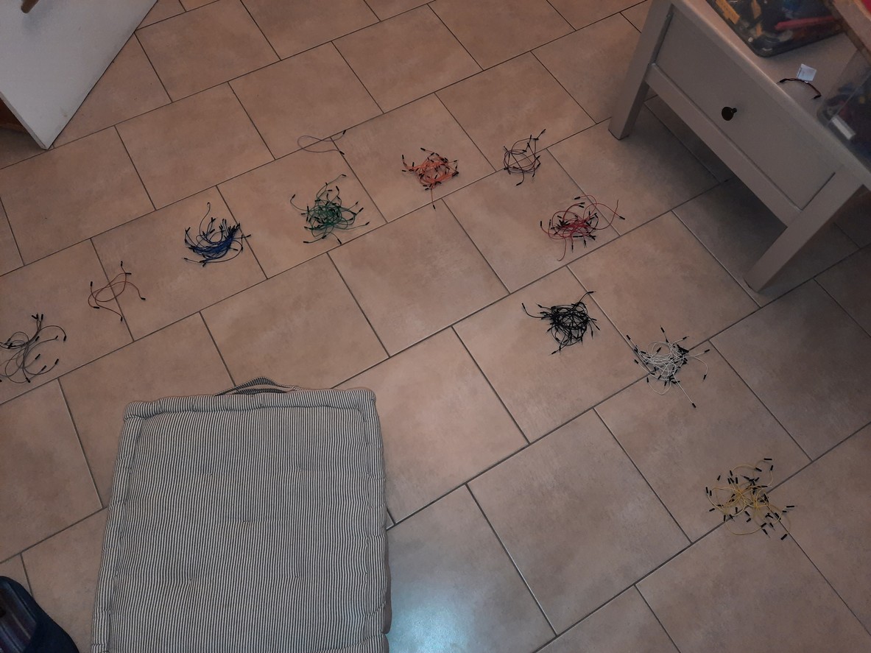
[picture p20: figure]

Lors du montage, on intercale un bouton entre les piles de 6V et la platine. C’est sur cette alimentation de 6V que le viennent s’alimenter le module Bluetooth et la carte. L’alimentation filaire sert à transmettre du courant uniquement aux moteurs, évitant ainsi le problème de perte de tension.

Image des fils triés par
couleurs lors de la
phase de câblage

Finalement le robot est construit, et câblé. Je me suis ensuite attelé à la programmation du robot. En m’inspirant fortement du programme précédent, j’ai créé une nouvelle télécommande et j’ai offert à l’utilisateur la possibilité de contrôler indépendamment les 3 trains de roues du robot. Un 7e

et 8e
boutons permettent de faire monter et descendre l’intégralité des trains en même temps. Enfin un bouton en croix permet de contrôler les déplacements du robot. Il peut avancer et reculer. Il peut aussi effectuer des rotation sur lui même vers la droite ou vers la gauche. Cela est rendu possible lorsque deux roues motorisées tournent dans un sens, et les deux autres tournent dans l’autre sens. Lors de la programmation, j’impose au programme d’envoyer des messages indiquant les ordres envoyés par la télécommande. L’idée est de suivre le comportement du robot.

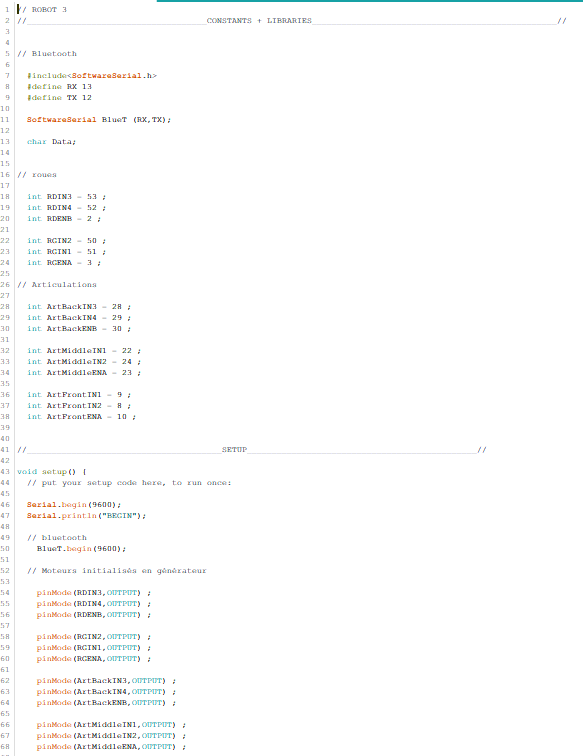
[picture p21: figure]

La dernière étape est de choisir des roues adaptées. L’idée est d’obtenir des roues ayant une faible adhérence au sol afin de réduire les forces qui s’exerceront lorsque les roues frotteront sur le sol lors de la montée ou descente des trains. Pour le train central, on utilise quatre disques très fin sans caoutchouc . Pour les trains avant et arrières qui sont motorisés, j’ai d’abord choisis des petites roues de type buggy. Le faible diamètre permettrais d’augmenter la capacité de montée du robot. Hélas, ces roues trop petites n’atteignaient pas le sol et le robot ne pouvait pas se déplacer. J’ai donc modifié cela en utilisant les anciennes roues de la première et deuxième version du robot. Mais en retirant les pneus. Là encore, le robot patine. Finalement j’ai remis les caoutchoucs sur les roues. Le robot se déplace enfin correctement. Heureusement, la faible épaisseur de ces roues permet de conserver les pneus tout en ayant une adhérence relativement faible avec le sol.

Aperçu du programme final
de contrôle du robot avec
Arduino

Ensuite, je suis passé aux essais. J’ai d’abord effectué deux tests. L’un avec le module Bluetooth branché en 5V, puis branché en 6V. On remarque que en 5V, il se déconnecte et le robot se retrouve bloqué dans son dernier mouvement. Il y a donc un risque de casse d’éléments. Pour cela, j’ai laissé le module avec une alimentation de 6V. Il n’y a plus de problème. On remarque que le robot est dépendant de l’alimentation filaire. Cette alimentation devrait pouvoir être remplacée par la suite par une pile de 7,5 ou 9V afin que le robot soit complètement indépendant.
Finalement, le robot se déplace correctement et chaque train de roues bouge normalement. Le robot peut se relever et s’affaisser, tourner, avancer et reculer. Il est terminé

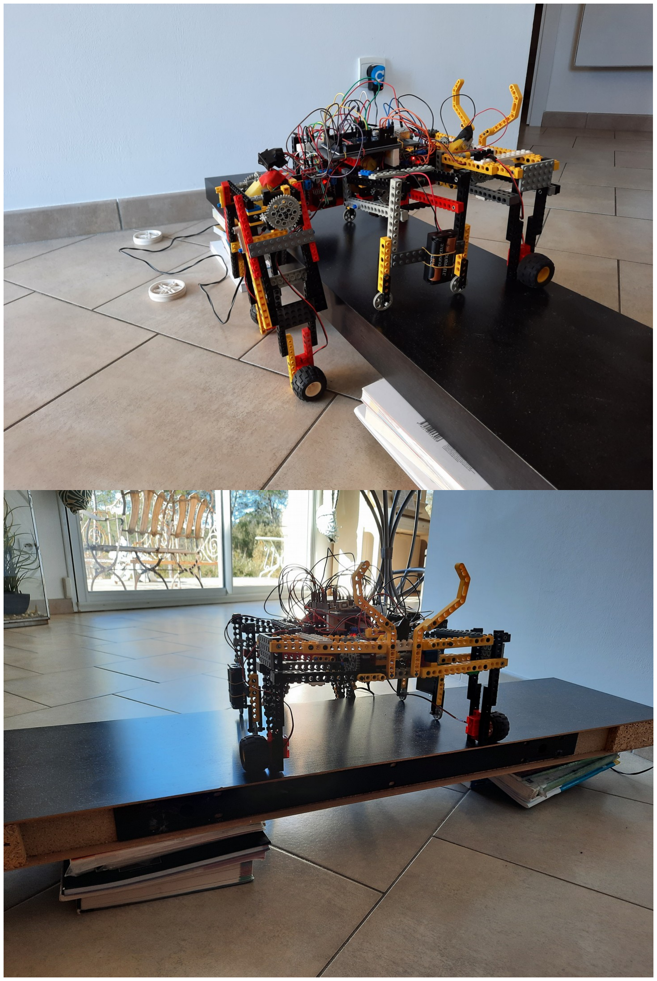
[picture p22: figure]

Photographie du robot final lors d’une phase test de montée (avant changement des roues)

Objectif de la séance

- modifier l’un des blocs d’alimentation du robot afin de l’alléger. (remplacer celui de 4 piles par un bloc de deux piles)
- Obtenir une pile qui remplace l’alimentation filaire
- Extension : chercher comment automatiser l’arrêt du robot lorsqu’il rencontre un obstacle (module de son)
- obtenir une nouvelle carte Mega pour remplacer la carte personnelle utilisée (à remplacer si assez de temps)

Partie 1 : modifier l’un des blocs d’alimentation

Grâce au matériel du professeur, le bloc d’alimentation de 4 emplacements a pu être remplacé par un bloc d’alimentation de deux emplacements pour les piles. L’usage de ce nouveau bloc est strictement le même. Son utilité est de réduire légèrement le poids, mais cela relève plus de l’esthétique final que de la mécanique ou de l’électronique.

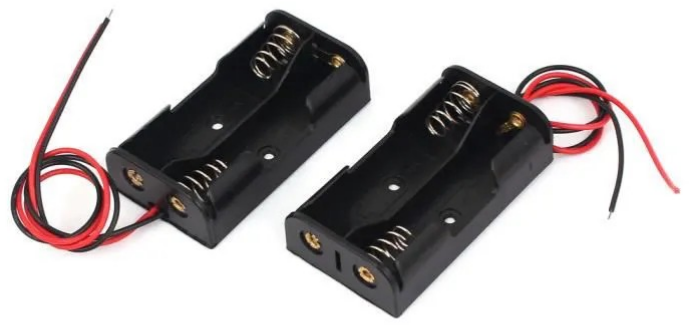
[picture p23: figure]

Partie 2 : Obtenir une pile qui remplace l’alimentation filaire

L’objectif ici est de remplacer l’alimentation filaire par une pile alcaline ou au lithium, capable de délivrer 7,5 ou 9V. Cela pourrai permettre de rendre le robot complètement libre de se déplacer sans être retenu par un câble qui peut en plus compromettre le mouvement lors des phases de montée ou de descente. Malheureusement, une telle pile n’est plus disponible dans le matériel de classe. Il faudra soit en trouver une par d’autres moyens, soit s’en dispenser.

Image des blocs d’alimentation utilisés

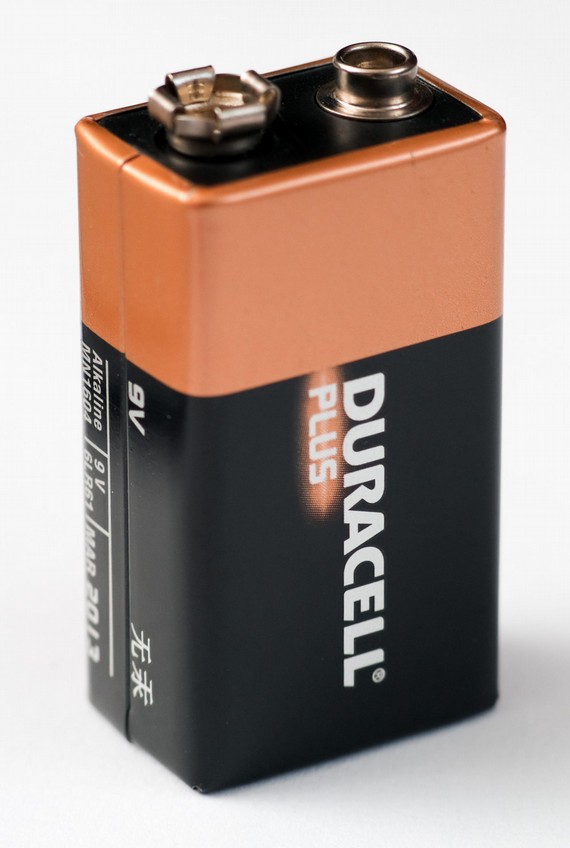
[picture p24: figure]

Partie 3 : Extension : chercher comment automatiser l’arrêt du robot lorsqu’il rencontre un obstacle (module de son)

L’objectif de cette extension est d’équiper le robot d’un système de détection des obstacles devant lui. Je me suis donc intéresser à l’utilisation du module de son. J’ai donc commencé par faire un premier câblage avec une carte Arduino UNO et le module concerné. Pour suivre j’ai commencé à programmer le module en cherchant comment évaluer les distances. Une partie de la séance à été consacré à de la recherche de documentation pour faire fonctionner ce module.
On remarque que certains problèmes se posent. Comment le robot doit-il réagir face à un obstacle ? S’arrêter ? Comment peut-il alors s’avancer pour le franchir ? Nous pouvons imaginer l’utilisation d’un bouton spécifique sur la télécommande permettant d’autoriser au robot le franchissement en déconnectant le module de son temporairement, etc

Image du type de pile souhaitée pour remplacer la connexion filaire

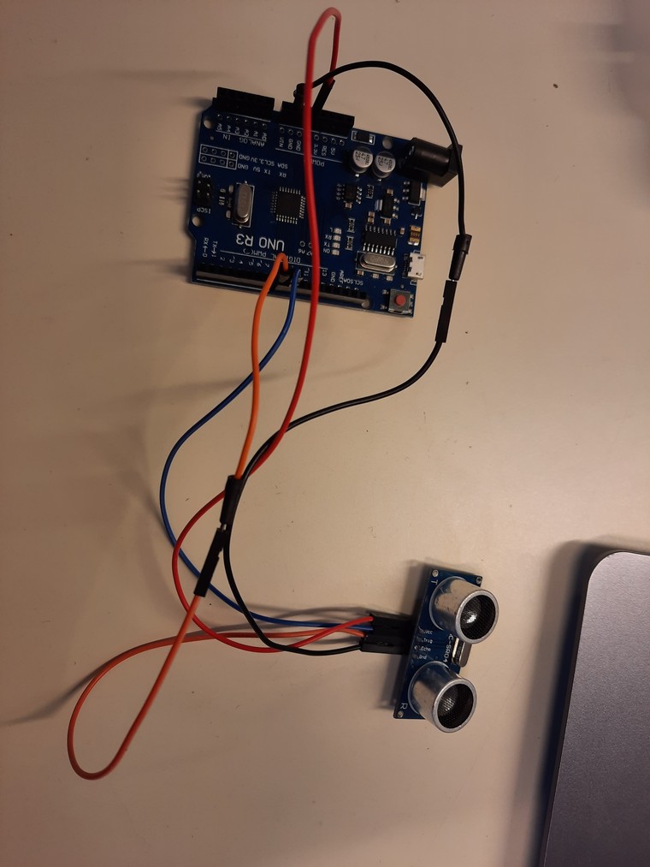
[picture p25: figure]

Photographie du premier
câblage du module de son

Conclusion

Suite au travail des vacances et de la séance, le robot en version complexe a pu être finalisé. La question de la pile se pose encore mais n’est pas indispensable, et le remplacement de la carte Mega personnelle par une carte spécifique n’est pas indispensable et relève de l’esthétique de l’appareil. La poursuite du projet tend donc vers l’utilisation potentiel du module de son. Certains problèmes commencent à apparaître, mais des solutions s’envisagent.

Pour la prochaine séance :

→ question persistante de la pile (dispensable)
→ évolution et mise en place du module de Son → question de l’esthétique et des finalités

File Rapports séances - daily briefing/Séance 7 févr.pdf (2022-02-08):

Azémard Maxime | PeiP2 Gp1

## Rapport séance 7 février 2022

### Travail personnel

Afin de terminer la construction du robot, je me suis occupé de terminer la partie programmation. Le problème soulevé à la séance précédente était que les servomoteurs ne prenaient pas en compte l’état du bouton à chaque instant. Afin de le résoudre, j’ai modifié le programme du robot en obligeant d’une part à ce que le téléphone envoie des caractères spécifiques pour l’état de chacun des boutons, et d’autre part, j’ai imposé au programme de récupérer les caractères envoyés par la télécommande en permanence (et pas seulement lorsque une modification d’état est effectuée). Finalement le programme fonctionne. Le robot est donc terminé en construction et en programmation. Il est temps de tester sa capacité à grimper un obstacle.

Malheureusement, le robot en son état actuel ne semble pas être capable de franchir un obstacle. En effet on observe lors de la phase de test que lorsque l’on relève l’une des articulations avant ou arrière, le robot s’écrase sur lui-même. Il s’agit du fait que les servomoteurs augmentent énormément le poids central de l’appareil. Et que ces servomoteurs ne sont pas assez puissant pour pouvoir se maintenir dans leur position d’arrêt. De plus il est très probable que les axes en sortie des servomoteurs se plient et se tordent avec la pression qu’ils subissent ce qui amplifie ce phénomène d’écrasement. Le robot, au lieu de maintenir sa position en soulevant une articulation, bascule vers l’avant. Lorsque l’articulation quitte enfin le sol, la capacité de montée est largement diminuée et il n’est plus en position horizontale mais affiche un fort angle d’inclinaison vers le bas.


Afin de pouvoir bloquer les servomoteurs dans leurs positions, il serait indispensable d’utiliser des vis sans fin. Hors elles ne s’adapteraient pas au montage. Il ne sera pas possible de recourir à cette solution. Il va donc falloir restructurer le robot.

Après démontage de la partie électronique, j’ai commencé par retirer les deux servomoteurs et les articulations associées. Il s’agit ici de réduire le poids de la structure globale. Il ne reste ainsi que les articulations avant et arrière. Il faut ensuite restructurer celles ci car avec l’absence du soutient des trains centraux, elles ne peuvent plus quitter le sol. J’opte donc pour modifier ces deux

Image de la version complexe du robot

Image traduisant l’écrasement du robot lorsque le train avant tente de se soulever articulations en retirant la partie verticale auxquelles sont rattachées les roues, pour les transformer en deux articulations équipées d’un seul axe avec deux paires de roues aux extrémités (une paires de roues avec fort diamètre, et une paire de roues plus petites). Lorsque les grandes roues sont au sol, les petites sont en l’air. Lors de la phase de montée, les petites roues, en basculant vers le sol, remplacent les grandes roues qui se soulèvent pour atteindre le haut de l’obstacle. Cela permet alors d’effectuer la phase de montée. Avec un système d’axe entre les deux paires de roues, on peut rendre motrices les 4 roues du système. En détachant le moteur de l’articulation arrière et en le rajoutant à l’avant, on obtient un moteur pour les roues de gauches et un autre pour les roues de droites (toujours sur le train avant). Il sera donc possible par la suite de faire tourner le robot dans différentes directions en faisant varier la vitesse de chaque roues.

A présent il faut rééquiper le robot de la carte et de l’alimentation. Puis réadapter la partie programmation. On note aussi qu’il sera nécessaire de modifie la télécommande du téléphone afin d’être adapté au nouveau robot et ses capacités.

### Objectif de la séance

1. câblage du nouveau robot
2. première programmation du robot
3. recherche de solutions afin de résoudre le problème des servomoteurs

### Partie 1 : câblage du nouveau robot

Pour commencer, il faut raccrocher la partie électronique au robot. J’ai tout d’abord retiré tous les câbles rattachés aux servomoteurs. Ensuite, j’ai branché les 4 moteurs aux deux ponts en H. Deux moteurs servent à la rotation des roues et les deux restants gèrent le mouvement des articulations. Afin de pouvoir modifier la vitesse de rotation des roues, j’ai relié les moteurs associés à des entrées PWM. Je n’ai pas installé l’électronique sur le robot mais je l’ai laissé de côté afin de pouvoir passer à la partie programmation.


Image de la
version simplifié
du robot et de son
câblage

### Partie 2 : première programmation du robot

Dans un 2e
temps, je me suis attelé à programmer le robot. Cela a demandé de s’inspirer très fortement du code déjà établit pour la première version du robot. Afin de faciliter la compréhension, certains noms de variables ont été modifiés et la partie du code destinée aux servomoteurs a bien évidemment été retiré. Une nouvelle télécommande a été créée sur l’application avec un bouton en croix pour le contrôle de la marche avant et arrière ainsi que les virages. Puis 4 boutons ont été placés pour diriger le mouvement des articulations. Chaque bouton envoie par le biais du Bluetooth un caractère spécifique qui désigne son état.

J’ai d’abord programmé le mouvement des roues : avancer, s’arrêter et reculer. Puis je me suis occupé du mouvement des articulations : monter et descendre.

avec Arduino

Bilan test :

Après avoir téléversé le programme, le robot avance et recule normalement. Les articulations fonctionnent et le robot est capable de grimper sur le rebord de la table. Il est fonctionnel. Il suffira de charger dessus le matériel électronique ainsi que de programmer rapidement la rotation du robot pour effectuer des virages et il sera terminé .

Programme de contrôle du robot simplifié


Image du robot
simplifié en étape de
montée (avant
câblage)

### Partie 3 : recherche de solutions afin de résoudre le problème des servomoteurs

Pour finir, j’ai recherché des solutions techniques afin d’essayer de rendre fonctionnel la première version du robot. Par suggestion du professeur, il serai possible d’en créer un deuxième à l’image de la première version. Pour cela il m’a fournit un double du matériel d’électronique : une carte, deux ponts en H, une platine d’essai, une alimentation et des câbles. L’idée ici est d’essayer de résoudre les problèmes rencontrés auparavant afin d’obtenir une version plus complexe et intéressante (version initiale). Les principaux problèmes viennent des servomoteurs qui ne se maintiennent pas et sont trop lourds. Il serai possible de bloquer l’articulation d’un servomoteur avec une vis sans fin. Pour cela il faut remplacer les servomoteurs par des moteurs classiques. De plus ce type de moteurs étant moins lourd, cela pourrai résoudre le problème de poids. On note que remplacer les servomoteurs par des moteurs classiques imposent l’utilisation d’un plus grand nombre de ports numériques. Il faudra peut être devoir utiliser une carte plus grande. De plus une jonction modélisé en 3D entre le moteur jaune et un axe Lego pourrai être nécessaire.

### Conclusion

Suite à cette séance, la deuxième version simplifiée du robot est fonctionnelle. Cela garanti le bon aboutissement du projet. De plus certaines options se présentent afin de résoudre les problèmes de la première version plus grosse et délicate.
Pour suivre il faudra tout d’abord compléter et finaliser la version simple en équipant le robot du bloc électronique et en modifiant légèrement son programme afin de lui octroyer certaines capacités. Ensuite il faudra consacrer du temps afin de résoudre les problèmes de la version complexe du robot, quitte à faire fusionner les deux versions afin de rendre le tout fonctionnel.

Pour la prochaine séance :

- compléter définitivement la version simple du robot
- restructurer les blocs servomoteurs pour essayer d’intégrer des vis sans fin
- retravailler la version complexe du robot (mécanique et électronique)

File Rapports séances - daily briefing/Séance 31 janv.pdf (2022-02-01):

Azémard Maxime | PeiP2 Gp1

Rapport Séance 31 Janvier 2022

Travail personnel

Les objectifs à faire en travail personnel étaient :
1. mettre en place le Bluetooth
2. terminer la construction du robot
3. faire un premier câblage complet du robot
4. programmer la télécommande

Pour commencer, je me suis intéressé à la connexion Bluetooth entre le téléphone et le module qui doit recevoir des informations. Il s’agit donc dans un premier temps de mettre en place un premier programme de connexion et d’appareillage du module afin de le configurer.


Ce programme permet de nommer le module « robot_Athlete » et de se connecter à lui. Nous pouvons à présent créer un programme principal.
Pour commencer à utiliser le Bluetooth, j’ai créé un programme qui permet d’allumer une led via ce système . J’ai d’abord créé une télécommande avec un bouton sur le téléphone, qui envoie deux type de message selon si l’on appuie ou non sur le bouton. Cela à pour conséquence l’allumage de la led.
Ce système servira par la suite à contrôler les moteurs.

Programme de configuration d’un module Bluetooth avec Arduino


Pour suivre, je me suis occupé de la création de la seconde partie du robot. J’ai tout d’abord recopié un symétrique de la partie avant avec des Legos en essayant d’homogénéiser les couleurs. Ainsi l’avant sera jaune et noir, et l’arrière rouge et noir. Ces couleurs permettrons par la suite de distinguer les différents moteurs, notamment dans le programme final. Je me suis aussi occupé de recréer les blocs moteurs avant et arrière afin de les optimiser au mieux. Une barre Lego a été rajoutée sur toute la longueur afin de solidariser l’ensemble et éviter une destruction dut aux forces d’écartements. Le robot est à présent terminé.
Lors d’un premier essai, on remarque que le moteur a des difficultés à soulever le poids de l’articulation avant. Il faut donc réadapter l’avant et l’arrière afin d’obtenir plus de puissance. J’opte donc pour l’utilisation d’engrenage. Après un premier test peut concluant avec deux engrenages de respectivement 8 et 24 dents, j’ai conservé deux engrenages de 8 et 40 dents afin d’obtenir une puissance de traction 5 fois plus grande. Mais on remarque une baisse considérable de la vitesse. Mais avec ce procédé, une tension de 3V suffit à faire marcher le mécanisme. Il ne devrait donc pas y avoir de problème avec les 6V du montage final.

Programme de contrôle d’une led par Bluetooth avec Arduino

Montage de contrôle d’une led par Bluetooth avec une carte Arduino et un module de connexion

Lors de cette finalisation j’ai aussi mis en place le dernier servomoteur. Avec l’aide du programme déjà établi lors des séances précédentes et de la même démarche de résolution (test des différents angles), j’ai rechercher les angles limites de ce servomoteur. De part la symétrie du robot on remarque que pour un même angle, l’un des servomoteur est dirigé vers le bas alors que l’autre est dirigé vers le haut. Il faut donc anticiper ce problème afin que les servomoteurs puissent marcher dans le même sens et rester au même niveau.
Enfin, j’ai mis en place un premier programme destiné à contrôler simultanément les deux servomoteurs. L’idée et qu’ils se positionnent systématiquement au même niveau en montant et descendant en même temps. Ce programme et destiné à permettre à l’utilisateur de contrôler en même temps l’intégralité des moteurs.


L’objectif suivant est de câbler tout le robot. Afin de rendre son utilisation plus simple, j’intercale un bouton classique en sortie des piles. Puis je câble et relie tous les composants entre eux. Malheureusement l’utilisation d’une plaque d’essai est nécessaire afin de brancher tous les câbles. Ce qui alourdi encore le montage. Afin d’alimenter les moteurs de la nouvelle partie du robot je choisis d’utiliser les ports analogiques de la carte. En effet ils se situent au plus proche de ces moteurs et ne serviront probablement pas à la récupération d’informations analogiques dans ce projet. On remarque que par manque de matériel, des câbles de couleurs rouges et noirs sont utilisés

Programmation de deux
servomoteurs avec Arduino

Image du robot grimpeur lors de la première phase de construction complète pour relier la carte au pont en H. Il faudra donc modifier cela à l’avenir. De plus certains câbles sont de trop petites longueurs.

Pour terminer, j’ai commencé la programmation finale du robot. Après avoir créé une télécommande spécialement pour contrôler le robot (composée d’un bouton de direction, de 4 séries de boutons de contrôle des articulations, et de 2 boutons pour contrôler l’ensemble des moteurs pour un même mouvement de monter ou descente) , je me suis consacré à faire marcher les roues et les moteurs classiques. Il est possible à présent de faire rouler le robot et de faire monter et descendre les trains avant et arrière avec une simple pression sur l’un des boutons de la télécommande. Mais les servomoteurs ne sont pas encore opérationnels. On remarque aussi que le module Bluetooth se déconnecte lorsque l’ordinateur est débranché. De plus les moteurs semblent marcher avec difficulté. Je suppose qu’ils soient sous alimenté du fait de la quantité de composants dans le robot. On remarque aussi que les servomoteurs seuls ne suffisent pas pour maintenir le robot.


Objectif de la séance

- Arranger le câblage des moteurs arrières (rouges)
- Résoudre le problème de déconnexion du module Bluetooth

Image du robot et de son équipement

- Résoudre le problème de manque de puissance dans les moteurs
- Programmer le mouvement des servomoteurs

Partie 1 : câblage des moteurs arrières

Pour commencer la séance, j’ai changé l’intégralité des câbles reliant le pont en H à la carte Arduino afin de ne pas avoir de confusion quand au rôle de ces câbles. J’ai donc retiré tous ceux de couleurs rouges et noires utilisés temporairement lors du premier montage, pour les remplacer par des marrons, oranges, bleus et jaunes. L’objectif ici étant de conserver la convention : rouge pour l’alimentation, noir pour la masse.

Partie 2 : Résoudre le problème de déconnexion du module Bluetooth

Afin de résoudre le problème lié au module, j’ai demandé l’assistance de l’un des professeurs. D’après le montage, le module est branché au 5V de la carte. Mais avec l’utilisation d’un voltmètre, on remarque que la tension obtenue par le module est inférieure à 5V. Il y a donc une perte dans le circuit. J’ai donc branché le module directement aux piles afin d’obtenir une tension suffisante pour le maintenir en marche. Une fois cette modification effectuée, il n’y a plus de problème de déconnexion.

Partie 3 : Résoudre le problème de manque de puissance dans les moteurs

Pour continuer, j’ai cherché à résoudre le problème de puissance des moteurs en difficultés. Encore une fois avec l’aide du professeur, nous nous sommes aperçu grâce au voltmètre que la tension obtenue au niveau des moteurs était bien plus faible que la tension délivrée en théorie par les piles dans le circuit. En effet, les moteurs reçoivent une tension de 1,7V. Il y a donc bien une perte d’énergie importante. Nous avons aussi remarqué que plusieurs des piles utilisées ne délivrent pas la tension indiquée. Après avoir changé les piles usagées par des nouvelles, le problème reste identique. Nous avons donc substitué le bloc d’alimentation de 6V par une pile de 9V afin d’envoyer plus de tension au circuit. On note que à ce moment là nous avons rebranché le module Bluetooth sur le 5V de la carte car celui ci ne supporte pas des tensions supérieures à 6V. Malgré ce changement radical, les moteurs restent toujours en difficultés. En effet, une baisse de 4V est enregistrée dans le circuit entre la tension de sortie d’alimentation et la tension au niveau des moteurs. Finalement nous utilisons un câble de branchement rattaché au courant du secteur qui permet de compléter la tension des piles afin d’obtenir une tension suffisante au bon fonctionnement du matériel. Avec ce procédé nous obtenons enfin des résultats convaincants. Malgré tout cette solution n’est que temporaire car elle contraint le robot à être rattaché en permanence à une prise extérieure.
Lors de cette étape, on remarque aussi des soucis liés au branchement de certains câbles qui se déconnectent. Il faudra donc utiliser du ruban adhésif afin d’empêcher ce type de problème à l’avenir.

Partie 4 : Programmer le mouvement des servomoteurs

Pour finir, je me suis consacré à continuer la programmation des moteurs et de la télécommande. L’idée est d’obtenir un mouvement réactif. Lorsque l’on appui sur un bouton, l’articulation dirigée par le servomoteur monte ou descend. Lorsqu’on relâche le bouton, le mouvement doit s’arrêter immédiatement. En m’inspirant des programmes établis auparavant lors du travail personnel, et du travail effectué à la première séance, je me suis établis à coder le servomoteur jaune situé à l’avant. Cependant le mouvement obtenu n’est pas encore le mouvement attendu. En effet lorsque j’enclenche mon bouton de montée, l’articulation s’active jusqu’à l’angle limite haut sans tenir compte de l’état du bouton. Il n’est pas suffisamment réactif et doit tenir compte de l’état permanent de ce bouton de pression.

Conclusion

De part le travail personnel et la séance de cours, le robot est à présent proche de son état final. La connexion avec le téléphone s’effectue et il est possible de contrôler certains moteurs avec une télécommande prête à l’emploi. Cependant certains problèmes persistent notamment la question de l’alimentation qui devra être résolue, la question du poids qui devrait pouvoir être encore optimisé en réduisant la taille de la plaque par exemple, la programmation des servomoteurs qui, malgré le fonctionnement actuel, ne correspond pas encore au résultat attendu, et les derniers ajustements concernant le câblage et la disposition des différents éléments.

Pour la prochaine séance :

→ terminer la programmation des servomoteurs
→ rechercher une plaque plus petite
→ résoudre le problème d’alimentation
→ ajustements
→ si possible faire un premier essai du robot pour tester son comportement et sa capacité à se déplacer, se transporter

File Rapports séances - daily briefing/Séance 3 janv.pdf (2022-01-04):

Azémard Maxime | PeiP2 Gp1

Rapport Séance 3 Janvier 2022

Suite au travail effectué pendant les vacances, nous avons à présent un train avant et un train central conçu en Lego. Pour rappel, le train avant est composé de deux moteurs (référence : « geekmoteur »). L’un fait fonctionner l’articulation et l’autre sert à la mise en marche des roues. Le train central est composé d’un servomoteur. L’utilisation d’engrenages permet de réduire le nombre de servomoteurs utilisés et d’articuler les deux bras de l’articulation en un même mouvement. Cette structure constitue la moitié du robot final.


Les points forts :


- l’articulation centrale comporte un unique servomoteur grâce à des engrenages
- l’utilisation de la vis sans fin permet de décharger le moteur du poids de la structure

Difficultés relevées :

- le servomoteur doit être complètement encastré dans la structure Lego afin d’être stable lors du mouvement
- l’articulation doit avoir des capteurs de contacts permettant d’envoyer un signal lorsque l’articulation est en position limite. Les capteurs de pression utilisés initialement étant trop peu sensible.
- il faut créer une pièce composée d’un emplacement de roue dentée et d’axe Lego afin de faire la jonction entre le servomoteur et l’axe de l’articulation centrale.

Objectifs :

Lors de cette séance, les objectifs sont donc :

### 1. Créer la pièce de jonction servo/axe avec un logiciel 3D 2. Faire le montage d’un moteur Lego et le programmer

Partie 1

Tout d’abord, je me suis intéressé à la modélisation de la pièce de jonction entre le servomoteur et l’axe Lego. Ma première idée était de créer en un bloc la pièce composée de la roue dentée d’un côté et d’un emplacement d’axe de l’autre.

Pour commencer je suis aller sur internet pour trouver les dimension d’un axe Lego. J’en ai tiré le document ci-joint :


Grâce à au schéma en haut à gauche, j’ai obtenu les dimensions d’un axe et j’en ai déduis les dimension de l’emplacement à modéliser.

Concernant la roue dentée, je n’avais pas les dimensions et le nombre de dents d’un embout de servomoteur. Afin de contourner ce problème, l’un des professeurs m’a suggéré l’idée d’utiliser un des axes en étoile originels du servomoteur et d’accrocher par dessus la pièce de jonction. Je me suis donc dirigé dans cette voie.

Afin de créer la pièce la plus optimisée, j’ai créé une première pièce cubique, avec un socle en étoile percé afin de connecter cette pièce à celle du servomoteur. Puis j’ai réduit les dimensions de la partie destinée à maintenir l’axe et j’ai aussi arrondi les angles. L’idée ici est de diminuer l’utilisation de matière lors de l’impression.

Voici le résultat :

Dessin
technique
représentant
les dimensions
des axes Legos


Pièce de jonction
modélisée en 3D

On remarque que pour pouvoir imprimer la pièce, il faut pouvoir exporter celle ci en fichier STL. Un problème rencontré a été la difficulté à convertir le fichier. De plus lors de l’exportation, les unités n’ont pas été respectées.
J’ai finalement envoyé cette pièce pour impression d’un premier exemplaire. Un second sera nécessaire lors de la création de l’autre partie du robot.

Partie 2

La fin de séance a été consacré à l’utilisation des moteurs. J’ai tout d’abord commencé par le montage en utilisant des piles, des transistors, la carte, la platine d’essai et un moteur Lego. J’ai commencé par placer tous les câbles comme si je faisais le montage pour deux moteurs, mais en en utilisant qu’un seul pour commencer.


Il aura été nécessaire lors du montage de tester la capacité des moteurs Lego en les reliant à l’alimentation de 6V. En effet mes premiers tests avaient été effectués avec une tension de 3V. J’ai pu conclure que ces moteurs supportaient bien cette nouvelle tension. Nous pouvons donc les utiliser sans problème.
On remarque que la tension de 6V de doit jamais être relié au 5V de la carte Arduino sous peine de détruire le composant. Il faut donc brancher l’alimentation des piles au VIN de la carte. De plus, la soudure de câble à l’alimentation (piles) est nécessaire afin de pouvoir les utiliser facilement. Il est donc possible maintenant de se dispenser de la platine d’essai. Enfin il faut toujours retirer une pile sur les quatre afin de ne pas détruire notre alimentation.
Une autre remarque est que une fois le montage complété, la place est considérablement réduite sur la carte. Il faudra donc utiliser les entrées analogiques pour brancher les 2 moteurs du train arrière.

Le montage ayant été terminé en même temps que la fin de séance, je me suis contenté de récupérer de nouveaux boutons de contact afin de pouvoir terminer la structure du train avant.

Conclusion

Lors de cette séance, la modélisation de la pièce de jonction va pouvoir permettre de terminer l’articulation centrale avant. Il ne suffira plus qu’à relier le servomoteur à la carte et programmer le mouvement.

Montage initial d’un
moteur Lego avec la
carte Arduino

Les boutons de pressions vont pouvoir être remplacés par des contacts sur le train avant et le futur train arrière.
Enfin le montage d’un moteur a pu être terminé.

Pour la prochaine séance

→ commencer la programmation des moteurs
→ commencer les recherches sur l’utilisation du Bluetooth
→ s’intéresser à comment fixer les contacts

L’objectif ici est de progresser dans la finalisation de la partie avant du robot.

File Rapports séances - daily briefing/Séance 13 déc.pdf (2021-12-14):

Maxime Azémard | PeiP2

Projet Arduino : Séance 2 du 13 Décembre 2020

Objectifs :

- Choix de l’articulation
- modélisation des premières pièces
- utilisation des moteurs Arduino

Partie 1 : Choix de l’articulation

A présent il est temps de décider le type d’articulation le mieux adapté afin de commencer la réalisation.

Nous avons vu précédemment que la création et l’utilisation d’un système d’articulation triangulaire était consommateur de servomoteurs. De plus la capacité des servomoteurs à relever un train de roues reste incertaine. Nous ne privilégierons pas cette solution en priorité

Afin de reproduire le comportement du rover sans s’éloigner trop du mouvement originel, nous allons chercher à modéliser le robot grimpeur selon ce plan :


→ Structure envisagée du robot :

Système d’articulation lego (source : matériel
personnel)

Mouvement; Schéma représentant la structure du robot; Structure centrale (socle); articulation; Roues (symbolisées par les flèches

On considère que lors de la montée, le train orange se lève le premier, puis les trains rouges simultanément, et enfin le train vert.

Partie 2 : modélisation des premières pièces

Lors de cette séance je me suis intéressé à la modélisation des principaux éléments de l’articulation. A savoir : la vis sans fin et l’engrenage

Modèle 3D d’une vis sans fin sur Onshape

Modèle 3D d’un engrenage sur Onshape

Partie 3 : Utilisation des moteurs Arduino

Les moteurs Arduino vont appliquer une force sur l’axe relié à la vis sans fin lors du mouvement d’une articulation. Il en faut quatre en tous afin de réaliser la structure complète du robot grimpeur.

Mon objectif de fin de séance a été de comprendre leur fonctionnement. Tout d’abord j’ai essayé d’en faire marcher un seul mais une erreur de montage empêche le moteur de se mettre en route.

Voici le programme utilisé (aperçu) :


L’objectif ici est de se familiariser avec l’utilisation de ces moteurs. La prochaine étape consiste à relier les 4 moteurs à la carte Arduino afin de les faire marcher tous ensemble. Par la suite, relier chaque moteur à une articulation constituera la base du fonctionnement du robot. On note que si les moteurs n’ont pas la puissance nécessaire pour soulever l’articulation, il sera possible de les remplacer par des moteurs 12 volts.

Conclusion :

Lors de cette séance, les premières pièces articulées ont été réalisées et la programmation des moteurs amorce l’étape de construction du mouvement.
Afin d’avancer dans cette construction (vacances) des articulations, plusieurs composants ont été récupérés : capteur Bluetooth, alimentation, transistor

Pour la prochaine séance :

- il sera nécessaire de finaliser la programmation des 4 moteurs
- il faudra réfléchir aux moyens de connecter les moteurs aux axes
- modéliser les pièces de la structure
- question du Bluetooth pour transférer des données
- imprimer les pièces de l’articulation
- (prototype Lego envisageable pour tester le mouvement)

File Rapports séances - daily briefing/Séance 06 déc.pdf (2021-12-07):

Maxime Azémard | PeiP2 Gp1

Rapport Séance 06 Décembre 2021

Objectifs :

- Trouver les solutions techniques capable de créer les articulations du robot
- question de l’articulation la mieux adaptée
- question des matériaux

Partie 1 : l’abaissement par servomoteurs

Suite à la proposition d’un professeur, une des solutions possibles afin de créer une articulation d’un train de roues serait l’utilisation de servomoteurs.
L’articulation se décomposerait alors selon le schéma suivant :

Servomoteurs; Moteurs

Dans un premier temps, Je souhaite faire marcher un servomoteur simple afin de me familiariser avec son comportement et comprendre commet l’insérer dans la structure du robot.

Montages et code :


Problèmes rencontrés :

- apprentissage de nouvelles fonctions :
Afin de comprendre l’utilisation d’un servomoteur, il a fallu utiliser les explications sur les sites suivants :
https://www.locoduino.org/spip.php?article62
https://www.youtube.com/watch?v=4w3_zbaPdcs

Le servomoteur nécessite l’utilisation d’une librairie particulière. Il est nécessaire d’utiliser la fonction « Servo X» afin que la carte détecte l’utilisation d’un servomoteur.
La méthode X.attach(Y) permet d’assigner un port d’utilisation au servomoteur.
La méthode « X.write » assigne une valeur d’angle au servomoteur
- paramétrage de la carte.
Toujours formaté pour la Xplain mini, le programme n’était pas reconnu par la carte UNO. L’utilisation de l’exemple de la librairie a été nécessaire pour desceller le problème.

Après résolution du problème on obtient un servomoteur capable de prendre un certain angle.

Application au projet : Avec plusieurs servomoteurs, il est possible de créer une articulation capable de modifier son angle d’inclinaison. Avec plusieurs de ces composants, il sera possible de créer les trains du robot. Ils pourront s’abaisser ou se détendre en appliquant certaines valeurs aux différents servomoteurs de l’articulation.

Partie 2 : D’autres moyen de créer une articulation

D’après mes propres recherches personnelles, différents autres types d’articulations sont envisageables :

→ une articulation avec deux axes matérialisées par des legos :


L’avantage de ce procédé est que l’utilisation d’un seul moteur pourrait générer le mouvement par l’utilisation notamment d’une vis sans fin. Ce procédés pourrait être envisageable.

→ une articulation en losange pour un train de roues pourrait aussi être envisageable. Le poids des roues est ainsi mieux répartie, mais le nombre de composants utilisés augmente encore.

Système d’articulation lego (source : matériel
personnel)

Après appel de M.Masson. Il serait possible de modifier le comportement global du robot afin de réduire le nombre de moteurs dans la structure.
Proposition : modifier le comportement de sorte à ce que le robot utilise les roues arrières afin de forcer contre la paroi lors des phases de montée. Un plateau pourrait s’élever en même temps que le train avant afin de conserver l’horizontalité.
→ Une idée pourrait être de transformer les roues du robot en des chenilles afin de pouvoir adhérer à la paroi :


Ce procédé s’éloigne du mouvement recherché avec une montée et descente des roues, mais il a l’avantage de permettre au train arrière de forcer en avant pour maintenir la structure en phase de montée. De plus il permettrait d’utiliser moins de servomoteurs. Ce système peut être envisagé

Partie 3 : question sur l’utilisation des matériaux et le nombre de composants

Il est aussi nécessaire de faire des recherches sur les matériaux à utiliser pour fabriquer le robot.
On remarque qu’une difficulté à prendre en compte pour la construction des articulations est le poids des roues à soulever.
On déduit que les servomoteurs dans le cas d’une articulation triangulaire (voir schéma) doivent porter une lourde charge et la forme de l’articulation amplifie cette charge appliquée aux servomoteurs.

Matériaux possibles :

→ Lego :

avantages : les pièces sont légères et facile à assembler Inconvénients : accessibilité aux pièces, solidité de la structure

→ pièces de métal :

avantages : solidité de la structure

Exemples de robots à chenilles (source : internet)

inconvénients : poids à soulever et assemblage des pièces. On note aussi que les pièces en métal nécessite l’utilisation du FabLab donc des contraintes horaires.

Solutions possibles : utilisation des legos afin de créer un premier prototype. Ensuite créer des articulations en métaux solides creux (tuyaux en métaux fins, etc) pour la structure finale.

Fin de séance :

Projet de programmation de deux servomoteurs afin d’essayer de matérialiser la faisabilité d’une articulation en forme triangulaire.
Si le servomoteur n’a pas la possibilité de porter un train de roues, l’utilisation d’un procédé différent sera nécessaire. Notamment la réduction du nombre de trains, et la modification du comportement du robot ou la transformation des roues en chenilles.

Pour la séance suivante, il serait intéressant de programmer définitivement un système de train de roues à articulations triangulaires afin de voir les possibilités de ce système. Il serait aussi nécessaire d’approfondir l’idée de M.Masson qui consiste à réduire le nombre de servomoteurs. Nous pourrions donc envisager de restructurer le robot afin d’intercaler des chenilles (en commençant par la programmation de 3 moteurs qui tournent dans le même sens) et de voir quelle forme est la plus adaptée pour grimper sur un obstacle.
La question de la stabilité du socle est à envisager.
Concernant les matériaux, l’utilisation de legos pour un premier prototype semble être une solution intéressante.

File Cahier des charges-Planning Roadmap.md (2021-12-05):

Cahier des charges : Athlete rover prototype

	Dans le cadre des futures missions spatiales et notamment celle du retour de l’Homme sur la Lune, la NASA développe actuellement le rover Athlete (All-Terrain Hex-Limbed Extra-Terrestrial Explorer ). Un robot de transport capable de se déplacer sur une multitude de terrains différents grâce à un système d’articulé des roues.

	Dans le cadre de la formation de Peip2, je souhaite travailler sur un robot capable de réaliser la montée et la descente d’un obstacle afin de simuler le comportement d’Athlete lors de son déplacement sur des reliefs escarpés. Le robot doit être manipulé à distance avec un système de télécommande capable de gérer les différentes paires de roues, ainsi que le déplacement du robot.
	Le projet pourra être étendu en prenant en compte la stabilité du socle destiné à transporter du matériel. L’automatisation du robot pourrait être envisagée (autre projet).

Objectif : robot capable de monter et descendre un obstacle de surface plate (type : marche d’escalier). 

Lors des phases de montée : le train avant se soulève, le robot s’avance, les roues avants prennent contact sur l’obstacle. Ensuite les roues centrales se soulèvent, le robot s’avance, le roues centrales prennent contact avec l’obstacle. Enfin le train arrière se relève. Le poids est ainsi porté par l’avant du robot qui s’avance jusqu’à ce que le train arrière prenne contact avec le sol. Le robot reprend ensuite sa hauteur par défaut

Lors des phases de descente : Le robot s’avance jusqu’à avoir le train avant dans le vide. Il s’abaisse jusqu’à se que les roues avants prennent contact avec le sol. Ensuite même démarche pour le train central et le train arrière.

Contraintes de réalisation :

Contraintes internes au robot :

- le robot doit être équipé de 3 paires de roues au minimum pour la gestion du centre de gravité.
- les trains avants et arrières doivent posséder des roues motrices et des pneus adhérents au sol afin de pouvoir pousser ou tracter le robot lors des phases de montée et de descente.
- le robot doit pouvoir communiquer à distance avec une télécommande. Un système de transfert de données est donc nécessaire (Bluetooth, …)
- chaque train doit être capable de fonctionner indépendamment des autres. Mais aussi tous ensemble. 
- Le poids et les matériaux utilisés doivent être pris en compte afin de permettre une meilleure gestion du centre de gravité.
- chaque train de roues doit être capable de s’abaisser et se relever. Son articulation nécessite une motorisation
- le train avant doit être capable d’orienter ses roues avants pour guider le robot.
- la programmation de la carte doit permettre de tester indépendamment chaque mouvement du robot. Ainsi que le mouvement global
- Le robot nécessite d’avoir avec lui une source d’énergie : pile,etc
- nécessité de modéliser les articulations des différents trains mobiles.
- nécessité d’une quantité importante de moteurs et roues

Contraintes externes

- délais : 8 semaines
- ouverture du FabLab
- budget

Tâches à effectuer :

1 Création /Programmation d’un train articulé
2  Création /Programmation des roues d’un train
3 Communication télécommande et carte
4 Multiplication des trains articulé
5 Création du socle et gestion de l’énergie
6 Assemblage final
7 (Système éclairage)
8 (Système d’alarme de stabilité)

Problèmes possibles :

- programmation du mouvement des trains de roues
- construction des articulations
- gestion du poids et centre de gravité (= stabilité)
- communication télécommande / carte Arduino

Évolutions potentielles :

- système d’alarme lorsque la plateforme dépasse un certain angle
- système de capteur ( de contact, ou d’ultrasons) pour détecter la distance de l’obstacle
- système d’éclairage

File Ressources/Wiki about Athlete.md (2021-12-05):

ATHLETE (All-Terrain Hex-Limbed Extra-Terrestrial Explorer) is a six-legged robotic lunar rover under development by the Jet Propulsion Laboratory (JPL). ATHLETE is a testbed for systems, and is designed for use on the Moon.[1]

The system is in development along with NASA's Johnson and Ames Centers, Stanford University and Boeing.[2] ATHLETE is designed, for maximum efficiency, to be able to both roll and walk over a wide range of terrains.[1]

Systems

The project aims to develop a multi-purpose system capable of docking or mating with special-purpose devices including refueling stations, excavation implements and/or special end effectors. The legs have six degrees of freedom (6-DOF) for generalized robotic manipulation.[1] Each ATHLETE is intended to have a payload capacity of 450 kilograms (990 lb),[1] in Earth's gravity with the capability of docking multiple ATHLETE vehicles together to support larger loads.

The ATHLETE is much larger than robotic systems previously used and has a diameter of around 4 metres (13 ft) and a reach of around 6 metres (20 ft).[1] Even with this larger size the project has allowed the facility for multiple units to be stowed and docked compactly for launch into an annular ring. This would mean that many vehicles can be efficiently stacked around a main payload on a single lander.[1]

The six 6-DOF legs allow more capabilities than other robotic systems such as Sojourner or the Mars Exploration Rovers. These mean that the slopes it could climb would be up to 35° on solid surfaces and 25° on soft surfaces,[1] such as the soft deposits of dust found on the Moon. Plans are to develop the system's capability of travel over rougher terrain and to increase the speed of ATHLETE to 10 kilometres (6.2 mi) per hour, 100 times faster than the Spirit and Opportunity rovers.[1]

Goals

The JPL is aiming for a 10-year life span,[1] and the capability for re-usable delivery vehicles would mean that the goal of "an affordable lunar-surface flight experiment that demonstrates this technology on the Moon and subsequently uses it as part of the Human Lunar Return campaign to perform the needed robotic or human vehicle functions on the lunar surface."[1]

ATHLETE's purpose is to support lunar exploration operations. One hypothetical mission scenario features a mobile, manned "base" supported by ATHLETEs capable of traversing thousands of kilometers and setting down temporarily to study interesting features along the way.[3]

Future improvements

Planning for the future of the ATHLETE include the ability to scale difficult obstacles by means of employing a launchable/releasable grappling hook and line which it will use to haul itself up even vertical slopes. There are also plans to introduce provisions for voice and gesture commands from suited astronauts in proximity to the ATHLETE, the ability to self deploy from their storage facilities and the capability for "autonomous footfall placement".[1] Work was also done to adapt the Tweel technology for use with the rover.

https://en.wikipedia.org/wiki/File:ATHLETE_(robot).jpg

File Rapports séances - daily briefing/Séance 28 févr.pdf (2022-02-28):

Azémard Maxime | PeiP2 Gp1

## Rapport séance 28 février 2022

### Travail personnel

Cette semaine, je me suis consacré à des finitions et des tests du robot. Je remarque plusieurs détails. Premièrement la puissance des moteurs est trop élevée et le robot subit de nombreux chocs sur ses articulations lors des déplacements. Il faut donc (si c’est possible sur ce type de moteur Lego Arduino) diminuer la puissance de ses moteurs de directions.
Ensuite, certains câbles se décrochent au niveau des articulations. Il faut donc les accrocher avec du ruban adhésif.
Pour suivre, j’ai augmenté a solidité des articulations en remplaçant les plaques Legos 2x12 par des plaques 4x12. Ce sont ces plaques qui maintiennent la structure en place. Il est indispensable qu’elles restent bien en place.
On remarque certaines faiblesses de la structure qui, face aux forces d’écartements ou de rotations, à une tendance à la déformation.


Objectif de la séance :

- Changer la connexion filaire par une pile 9V
- réduire la puissance des moteurs de déplacements
- ajuster les finitions des câbles
- Organiser le Github

Image de la plaque de
renfort 4x12 sur le
train central

Partie 1 : Changer la connexion filaire par une pile 9V

Pour commencer, j’ai demandé une pile de 9V afin de remplacer la connexion filaire du robot. Il est maintenant capable de se déplacer n’importe où sans être retenu. Cette pile est accrochée sur une des articulations du train central avec des élastiques.


Partie 2 : Réduire la puissance des moteurs de déplacements

Pour suivre, j’ai cherché à réduire le phénomène de secousses que subit le véhicule en réduisant la puissance des moteurs.
J’ai tout naturellement commencé par réduire les valeurs sur les entrées PWM rattachées aux moteurs de déplacement. Mais aucun effet immédiat ne s’est produit. J’ai tout d’abord pensé que les moteurs n’étaient pas adaptés à une réduction de puissance.
Après consultation avec le professeur, je me suis rendu compte que j’utilisais la mauvaise fonction. La fonction digitalWrite() ne prend que les valeurs 0 ou 1 ce qui équivaut à envoyer systématiquement le maximum de puissance lorsque la valeur est 1. Il faut donc remplacer cette fonction par AnalogWrite(). Dès lors la vitesse se réduit considérablement. Ce qui réduit les secousses. On remarque que lors des rotations, il faut appliquer des valeurs plus élevées pour les moteurs car la force à appliquer est bien plus forte que lors de déplacement latéraux. En effet certains tests de rotations se sont soldés par des échecs lorsque les moteurs étaient trop faibles.

Partie 3 : Ajuster les finitions des câbles

Pour finir, je me suis occupé de consolider les raccords des différents câbles avec du ruban adhésif. En effet, les câbles sans embout spécifiques mâles ou femelles ont tendance à se détacher lors du mouvement. Particulièrement au niveau du train central, entre l’alimentation de la pile de 3V droite et la rallonge qui se connecte à la platine.
On remarque aussi qu’un des câbles verts dirigeant les roues gauches se détache facilement. Il doit donc aussi être attaché plus solidement.

Image de la pile 9V sur
le train central

Partie 4 : Organiser le Github

A présent le robot est opérationnel. Le reste de la séance a donc été consacré à l’organisation du site Github lié au robot. J’ai rajouté plusieurs rubriques :
la première intitulée « Codes » est consacrée au stockage des différents programmes utilisés pour les trois robots. Les programmes de tests spécifiques, et les programmes de contrôle des robots (Attention : le programme « Robot3_Programme.ino » n’est pas encore mis à jour).
La seconde est la rubrique « Modélisation de pièces CAO ». Ici se situent les deux fichiers de pièces 3D imprimées pour le projet.
Enfin la rubrique « Vidéos et images » accueillent un ensemble d’images récoltées au cours du projet et une vidéo de la 2e
version du robot.


Conclusion : Suite à cette dernière séance, le robot est fonctionnel et prêt à être présenté et à être filmé. A l’avenir certaines améliorations pourraient être envisagées comme la détection d’obstacle par retour d’onde sonore, la détection des angles limites par capteur de pressions, ou l’automatisation des mouvements de montée ou de descente. Mais par défaut de temps, je n’envisage pas de commencer l’un de ces projets qui soulèvera de nouveaux problèmes mécaniques et informatiques.


Image de la 3e
version
du robot à l’état final

Image des
différentes
rubriques
sur Github

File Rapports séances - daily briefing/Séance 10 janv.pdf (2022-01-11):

Azémard Maxime | PeiP2 Gp1

Projet Arduino : Séance du 10 Janvier 2022

Objectif :

- Préparation de l’oral :
- finalisation de la mise en marche des moteurs (moteurs simples et servomoteur) ;
- montage des différentes parties pour la présentation
- Réajustement de la pièce de jonction Lego/servo
- Programmation et montage Bluetooth

Partie 1 : Préparation et finalisation de l’oral

1. Mise en marche des moteurs

Grâce au montage de la semaine précédente, et en rajoutant un 2e
moteur, il est à présent
possible de faire fonctionner le train avant du robot. L’un des deux moteurs est relié aux roues et l’autre est rattaché à la vis sans fin pour faire fonctionner l’articulation.
Dans un premier temps nous utilisons un programme simple faisant tourner en boucle l’étape de rotation des roues (premier moteur) puis un arrêt, puis l’articulation monte (deuxième moteur) durant un certain temps « t », elle s’arrête, enfin elle redescend durant le même temps « t ». On remarque lors de cette étape que la distance parcourue lors de la descente est plus grande que la distance parcourue lors de la montée. Cela est provoqué par le poids qui entraîne l’articulation vers le bas. Lors de la descente, le poids de la structure et le mouvement son dans le même sens. Ils s’ajoutent. Lors de la montée, le poids est en opposition à la force exercée par le moteur et la distance parcourue devient plus courte.
Le problème qu’il se pose alors est lorsque l’articulation atteint l’angle limite bas. En effet, le moteur est bloqué et exerce une force sur la structure qui le dégrade. Afin de résoudre ce problème pour la présentation. Il a été nécessaire de partir d’un angle intermédiaire et d’indiquer un temps de monter et de descente très court afin de ne pas atteindre l’angle limite. De plus on augmente légèrement le temps lors de la montée par rapport à celui de la descente. Par la suite cette articulation sera équipée de capteur (obtenu au cours précédent) afin d’envoyer un signal lorsqu’un angle limite est atteint.


Montage des deux moteurs
Lego avec une carte Arduino et l’alimentation

Concernant l’articulation centrale avant, une fois la pièce de jonction fixée sur une étoile d’axe de servomoteur, il est possible de brancher le servomoteur à l’axe Lego. On remarque deux problèmes. Tout d’abord, les dimensions de la pièce imprimée sont incorrectes et trop petites. L’axe ne rentre pas bien dans son emplacement et les perçages ne sont pas visible. Cela est du à l’imprécision de la machine à cette échelle. Il a donc fallu retravailler la pièce avec des outils adaptés comme une perceuse ou des clous (fait en travail personnel).
Il faut à présent mettre en marche le servomoteur avec le programme de la première séance modifié afin qu’il monte et descende en boucle. Il faut à présent trouver les angles limites. En effet l’articulation centrale avant ne sera pas composée de capteur. Il faut donc partir d’un angle intermédiaire, c’est à dire 70°, puis chercher les angles limites lors de la montée et lors de la descente des roues. Il s’avère que ces angles limites sont 2° et 120°.

2.Montage des différentes parties pour la présentation

Afin de présenter lors de l’oral les différents mouvements obtenus du robot, il a d’abord été nécessaire de monter l’articulation avant avec l’articulation centrale avant. Afin que le robot ne tombe pas lors de la phase de présentation, nous le fixons ensuite sur un socle surélevé Lego. Les différents câbles des moteurs ont été reliés à la carte. On remarque que des rallonges sont nécessaires afin de ne pas gêner le mouvement. Enfin j’ai créé un programme unique comportant les deux sous programmes. Celui qui dirige les moteurs du train avant et celui qui dirige le servomoteur du train central. (Il faut ici faire attention au sens des roues lorsqu’elle se mettent en marche) Lorsque l’on téléverse le programme dans la carte et que l’on fournit de l’énergie grâce aux piles, le mécanisme se met en marche. L’articulation du train central se met en marche en effectuant un cycle. Puis lorsqu’il s’arrête les roues avants s’activent quelques secondes. Puis s’arrêtent elles aussi. L’articulation avant monte, fait une pause, puis redescend. Enfin ce cycle recommence.
On constate que lorsque le servomoteur ne commence pas son cycle en position haute, il a des difficultés à remonter avant d’entamer le premier cycle. Ensuite il se comporte normalement.


Image de la partie avant du robot, maintenu sur son socle


Programme dirigeant l’intégralité des moteurs pour la présentation

Le montage et le programme étant fonctionnels pour la présentation, il est nécessaire à présent de retravailler la pièce de jonction afin de résoudre le problème de dimension. Cela sera nécessaire pour la création de la partie arrière du robot.

Partie 2 : Réajustement de la pièce de jonction Lego/servo

Afin de résoudre les problèmes de dimensions, j’ai consacré une partie de la séance au réajustement de la pièce 3D imprimé afin de faire la jonction entre un axe Lego et la roue dentée du servomoteur.
J’ai donc réévalué toutes les valeurs de la croix en les arrondissant à la valeur supérieure. De plus tous les perçages avaient un rayon de 1mm. Je les ais modifié afin que le rayon soit de 2mm. J’ai constaté que les esquisses de perçages s’étaient décalées lors de la modification du rayon. Il a donc fallu récupérer la distance entre le centre initial d’un perçage et le centre de la pièce afin de la reporter sur toutes les nouvelles esquisses de perçage. A présent, elles se sont bien réalignées.
Avec cette modification, il a aussi été nécessaire de réduire la valeur de l’arrondi sur le bord de la pièce car celui ci empiétait trop sur les nouveaux perçages.
La pièce a été envoyée pour impression.


Partie 3 :Programmation et montage Bluetooth


A présent, notre robot possède des articulations fonctionnelles. Il est nécessaire de mettre en place le système Bluetooth afin de pouvoir il transmettre des informations. Par la suite ce système devra être capable de piloter à distance chaque articulation et moteur.
Pour commencer je me suis intéressé à la documentation internet et au cours dans le but de mieux comprendre comment effectuer la connexion entre l’appareil Bluetooth et le téléphone.
J’ai ensuite commencer par le montage :

Représentation de la première version de la pièce de jonction en vu de dessus

Représentation de la seconde version de la pièce de jonction en vu de dessus


Pour suivre, j’ai commencer le programme de connexion entre les deux appareils. Il s’agit ici de configurer notre appareil Bluetooth pour qu’il communique avec le téléphone. Ce programme n’est malheureusement pas encore fonctionnel.
Par la suite il faudra créer un programme annexe qui contiendra les instructions relatives aux commandes du robot afin de le contrôler.

Conclusion

A l’issu de cette séance, toutes les articulations avants du robots sont fonctionnelles. Le programme actuel présenté lors de la soutenance les maintient dans une boucle infinie qui impose une montée et descente continue. Lorsque le système Bluetooth sera opérationnel, ce programme deviendra superflu. En effet ces articulations seront pilotées manuellement. On rappelle que le socle utilisé lors de la présentation sera aussi retiré lorsque le train arrière sera finalisé.
Nous avons aussi recréé la pièce de jonction pour le train central arrière. Ce qui permettra de diminuer la difficulté de conception de l’articulation associée.

Pour la prochaine séance

→ il faudra vérifier la validité de la pièce imprimée
→ il faudra continuer la connexion Bluetooth/téléphone
→ (envisager la mise en place des capteurs sur la partie avant et de les relier à la carte afin de résoudre le problème d’angle sur le train avant)

Représentation du montage du module Bluetooth sur la carte Arduino

(Attention: les ports branchés au TX et RX ne sont pas les mêmes que ceux utilisés par le robot)

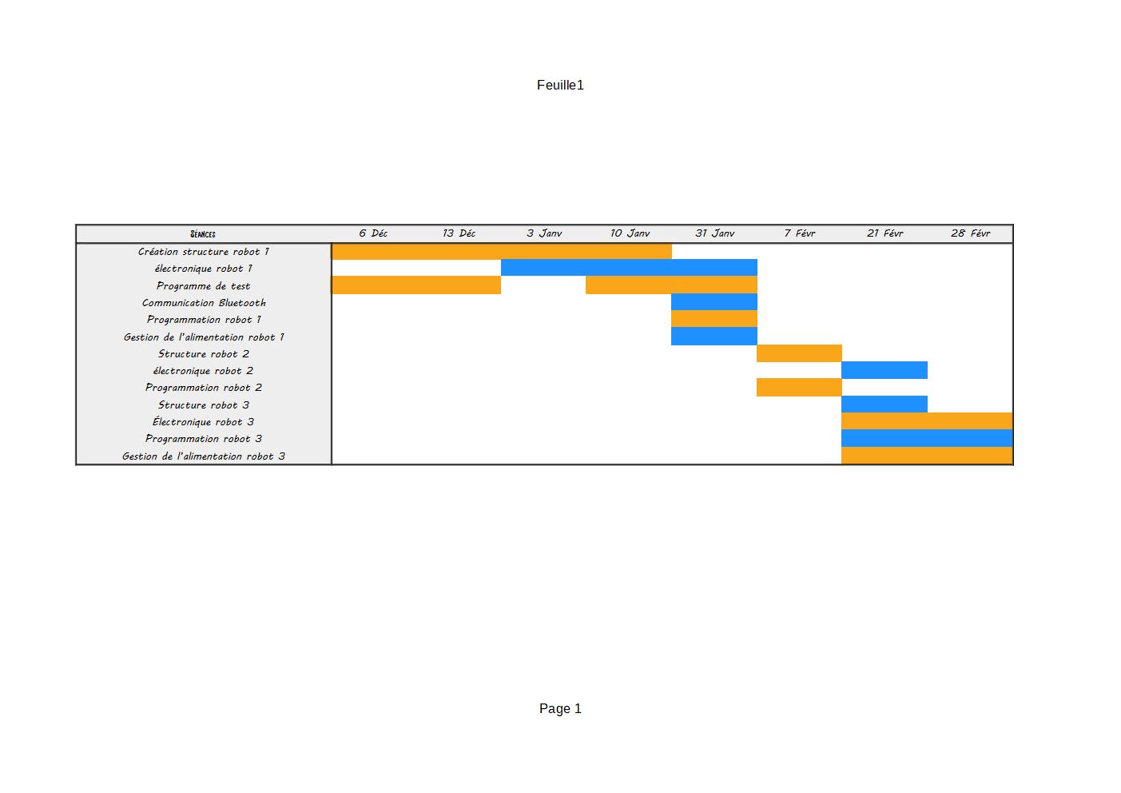
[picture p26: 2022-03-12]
Diagramme de Gant final.jpg

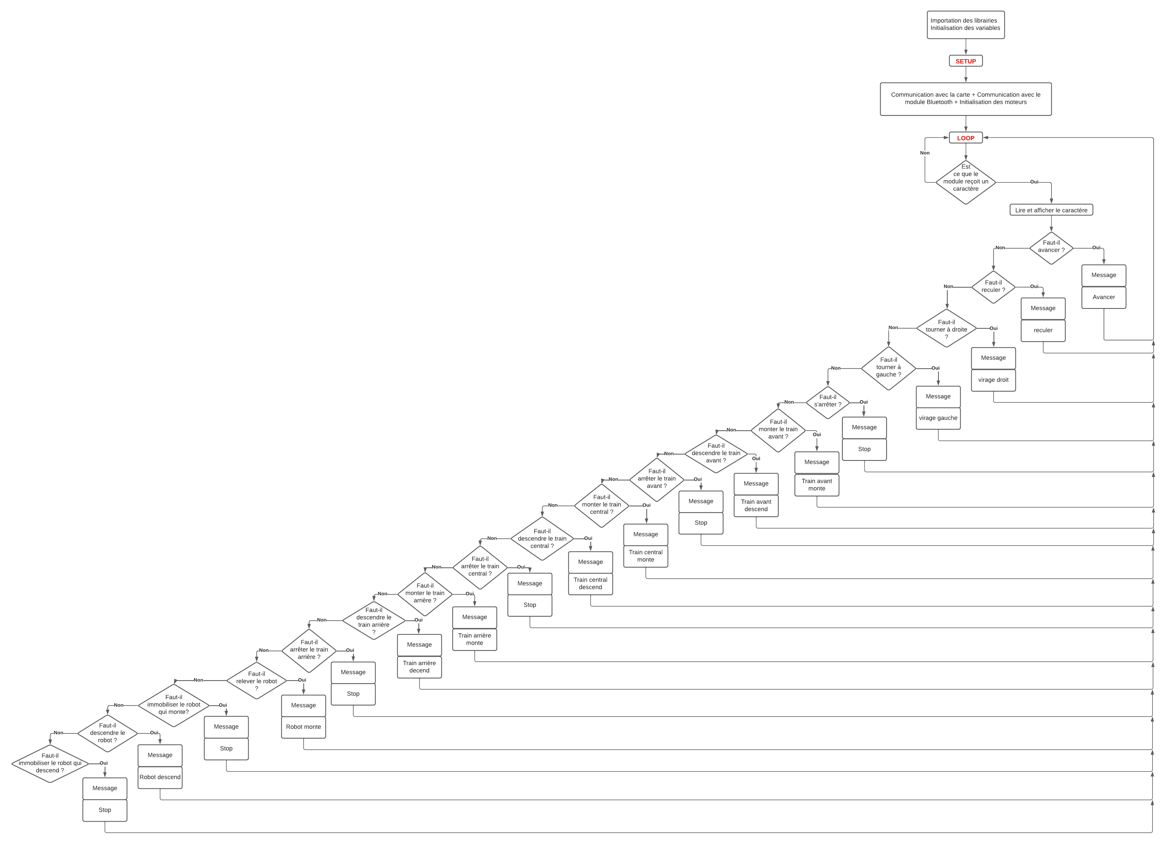
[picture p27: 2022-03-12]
Codes/Logigramme Robot 3.png

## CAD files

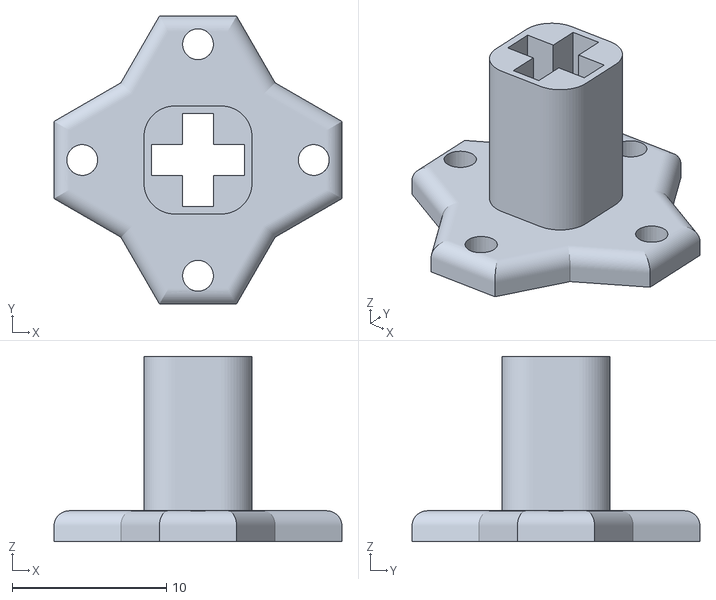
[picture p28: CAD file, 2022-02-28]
Modélisation de pièces CAO/Part Studio 1 - jonction LegoServo.stl
18.7 x 18.7 x 12.0

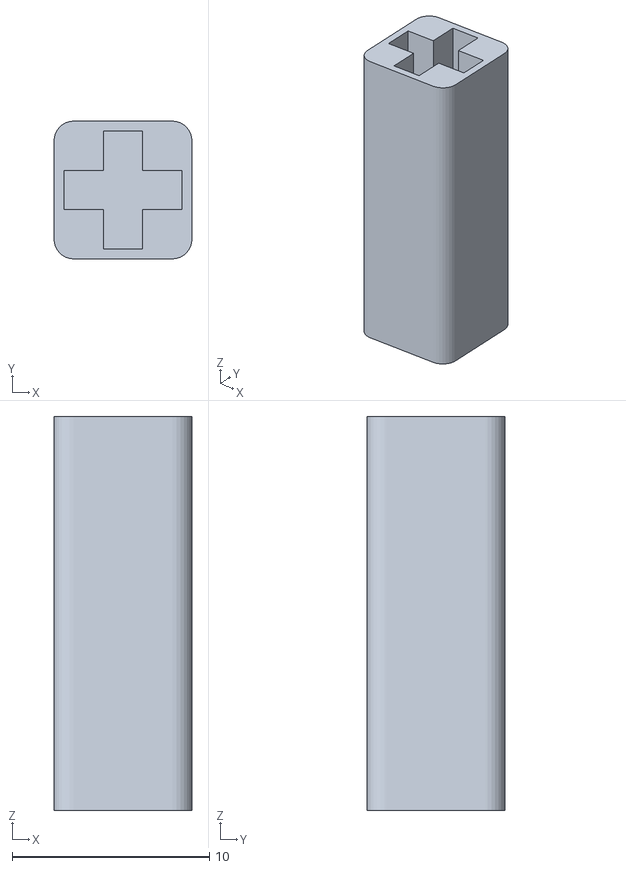
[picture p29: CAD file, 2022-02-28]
Modélisation de pièces CAO/Vis entre lego et moteur jaune.stl
7.00 x 7.00 x 20.0

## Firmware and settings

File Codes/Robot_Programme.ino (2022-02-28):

//    PROGRAMME ROBOT        //

// =============================================================================================================//

//------------------------- LIBRAIRIES ---------------------------------------//

#include <Servo.h>;
#include<SoftwareSerial.h>
#define RX 13
#define TX 12

//-----------------------------------------------------------------------------//
// Moteurs

  // bloc jaune

    // roues
    int JENA = 9 ;
    int JIN1 = 4 ;
    int JIN2 = 5 ;
    
    // articulation
    int JENB = 10 ;
    int JIN3 = 6 ;
    int JIN4 = 7 ;


  // bloc rouge

    // roues
    int RENA = 19 ;
    int RIN1 = 18 ;
    int RIN2 = 17 ;

    // articulation
    int RENB = 14;
    int RIN3 = 16;
    int RIN4 = 15 ;


// Servos 

  Servo monServoJaune;
  Servo monServoRouge;

  int positionServoJaune ;
  int positionServoRouge ;

  boolean jauneMonte = false;
  boolean jauneDescente = false;

  boolean rougeMonte = false ;
  boolean rougeDescente = false;


// Bluetooth

SoftwareSerial BlueT (RX,TX);

char Data;

//============================================================== SETUP =======================================================================//

void setup() {
  Serial.begin(9600);
  Serial.println("BEGIN");

  // bluetooth
  BlueT.begin(9600);

  // Moteurs

  /* RAPPEL
   * ENA: puissance
   * INx INy: sens
   */
   
  pinMode(JENA,OUTPUT);
  pinMode(JIN1,OUTPUT);
  pinMode(JIN2,OUTPUT);
  
  pinMode(JENB,OUTPUT);
  pinMode(JIN3,OUTPUT);
  pinMode(JIN4,OUTPUT);

  pinMode(RENA,OUTPUT);
  pinMode(RIN1,OUTPUT);
  pinMode(RIN2,OUTPUT);
  
  pinMode(RENB,OUTPUT);
  pinMode(RIN3,OUTPUT);
  pinMode(RIN4,OUTPUT);

  // Servos

  monServoRouge.attach(11);  
  monServoJaune.attach(3);

}

//============================================================== LOOP =======================================================================//

void loop() {

  positionServoJaune = monServoJaune.read();
  positionServoRouge = monServoRouge.read();



  
  
  if(BlueT.available()){ // si BlueT disponible
    Data = BlueT.read();
  }
    Serial.print("Data is : ");
    Serial.println(Data);


    if (Data == '1'){
      Serial.println("En avant");

      // Moteur roues Jaunes
      digitalWrite(JIN1,LOW);
      digitalWrite(JIN2,HIGH);
      // Moteur roues rouges
      digitalWrite(RIN1,HIGH);
      digitalWrite(RIN2,LOW);
      
      digitalWrite(JENA,255);
      digitalWrite(RENA,255);
    }
    
    if (Data == '3'){
      Serial.println("En arrière");

      // Moteur roues Jaunes
      digitalWrite(JIN1,HIGH);
      digitalWrite(JIN2,LOW);
      // Moteur roues rouges
      digitalWrite(RIN1,LOW);
      digitalWrite(RIN2,HIGH);
      digitalWrite(JENA,255);
      digitalWrite(RENA,255);
    }

    if (Data == 'A'){
      Serial.println("Jaune avant monte");
      digitalWrite(JIN3,LOW);
      digitalWrite(JIN4,HIGH);
      digitalWrite(JENB,255);
    }

    if (Data == 'a'){
      Serial.println("Jaune avant descend");
      digitalWrite(JIN3,HIGH);
      digitalWrite(JIN4,LOW);
      digitalWrite(JENB,255);
    }


    

  if (Data == 'b') {
    jauneMonte = false ;
  }

  if (Data == 'B' or jauneMonte)   {
    Serial.println("Servo jaune monte");
    jauneMonte = true ;
    if (positionServoJaune >=10){
         positionServoJaune -= 1 ;
         monServoJaune.write(positionServoJaune);
     }
   }
    
  if (Data == 'f') {
    jauneDescente = false ;  
  }
if (Data == 'F' or jauneDescente==true) {
      Serial.println("Servo jaune descend");
      jauneDescente = true ;
      if (positionServoJaune <=100){
         positionServoJaune += 1 ;
         monServoJaune.write(positionServoJaune);
       }
    }



 if (Data == 'c') {
    rougeMonte = false ;
  }

  if (Data == 'C' or rougeMonte)   {
    Serial.println("Servo rouge monte");
    rougeMonte = true ;
    if (positionServoRouge >=10){
         positionServoRouge -= 1 ;
         monServoRouge.write(positionServoRouge);
     }
   }
    
  if (Data == 'g') {
    rougeDescente = false ;  
  }
if (Data == 'G' or rougeDescente==true) {
      Serial.println("Servo rouge descend");
      rougeDescente = true ;
      if (positionServoRouge <=100){
         positionServoRouge += 1 ;
         monServoRouge.write(positionServoRouge);
       }
    }
/*  PARTIE RETIRE 
    if (Data == 'b'){
      Serial.println("Servo jaune monte");
      
      for (positionServoJaune ; positionServoJaune <= 120 ; positionServoJaune++){
        monServoJaune.write(positionServoJaune);
        delay(40);
      }
    }
JUSQUE LA !!!!

*/



    if (Data == 'C'){
      
    }

    if (Data == 'c'){
      
    }

    if (Data == 'D'){
      Serial.println("Rouge avant monte");
      
      digitalWrite(RIN3,LOW);
      digitalWrite(RIN4,HIGH);
      
      digitalWrite(RENB,255);
    }

    if (Data == 'd'){
      Serial.println("Rouge avant descend");
      
      digitalWrite(RIN3,HIGH);
      digitalWrite(RIN4,LOW);
      
      digitalWrite(RENB,255);
    }

    if (Data == 'S'){
      
    }

    if (Data == 's'){
      
    }

    if (Data == '0'){
      Serial.println("STOP !");
      digitalWrite(JENA,0);
      digitalWrite(RENA,0);
    }

    if (Data == 'r'){
      Serial.println("STOP !");
      digitalWrite(JENB,0);
      digitalWrite(RENB,0);
      
      //positionServoJaune = monServoJaune.read();
      //monServoJaune.write(positionServoJaune);
      
    }
    
  
}

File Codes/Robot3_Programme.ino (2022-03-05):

// ROBOT 3
//____________________________________CONSTANTS + LIBRARIES_________________________________________________//


// Bluetooth

  #include<SoftwareSerial.h>
  #define RX 13
  #define TX 12
  
  SoftwareSerial BlueT (RX,TX);
  
  char Data;


// roues

  int RDIN3 = 53 ;
  int RDIN4 = 52 ;
  int RDENB = 2 ;

  int RGIN2 = 50 ;
  int RGIN1 = 51 ; 
  int RGENA = 3 ;

  int vitesse = 100 ;
  int vitesseRotForte = 230 ;
  int vitesseRotFaible = 40 ;

// Articulations

  int ArtBackIN3 = 28 ;
  int ArtBackIN4 = 29 ;
  int ArtBackENB = 30 ;

  int ArtMiddleIN1 = 22 ;
  int ArtMiddleIN2 = 24 ;
  int ArtMiddleENA = 23 ;

  int ArtFrontIN1 = 9 ;
  int ArtFrontIN2 = 8 ;
  int ArtFrontENA = 10 ;


//_______________________________________SETUP______________________________________________//

void setup() {
  // put your setup code here, to run once:

  Serial.begin(9600);
  Serial.println("BEGIN");

  // bluetooth
    BlueT.begin(9600);

  // Moteurs initialisés en générateur

    pinMode(RDIN3,OUTPUT) ;
    pinMode(RDIN4,OUTPUT) ;
    pinMode(RDENB,OUTPUT) ;
    
    pinMode(RGIN2,OUTPUT) ;
    pinMode(RGIN1,OUTPUT) ;
    pinMode(RGENA,OUTPUT) ;
    
    pinMode(ArtBackIN3,OUTPUT) ;
    pinMode(ArtBackIN4,OUTPUT) ;
    pinMode(ArtBackENB,OUTPUT) ;

    pinMode(ArtMiddleIN1,OUTPUT) ;
    pinMode(ArtMiddleIN2,OUTPUT) ;
    pinMode(ArtMiddleENA,OUTPUT) ;

    pinMode(ArtFrontIN1,OUTPUT) ;
    pinMode(ArtFrontIN2,OUTPUT) ;
    pinMode(ArtFrontENA,OUTPUT) ;

}

//__________________________________________LOOP_____________________________________________//

void loop() {
  // put your main code here, to run repeatedly:

    if(BlueT.available()){ // si BlueT disponible
      Data = BlueT.read();
    
      Serial.print("Data is : ");
      Serial.println(Data);


      //DIRECTIONS

      if (Data == '1'){
        Serial.println("En avant");

        digitalWrite(RDIN3, HIGH) ;
        digitalWrite(RDIN4 , LOW) ;
      
        digitalWrite( RGIN2 , LOW) ;
        digitalWrite(RGIN1 , HIGH) ;
        
        analogWrite(RGENA , vitesse) ;
        analogWrite(RDENB , vitesse) ;
      }

      

      if (Data == '3'){
        Serial.println("En arrière");

        digitalWrite(RDIN3, LOW) ;
        digitalWrite(RDIN4 , HIGH) ;
      
        digitalWrite( RGIN2 , HIGH) ;
        digitalWrite(RGIN1 , LOW) ;
        
        analogWrite(RGENA , vitesse) ;
        analogWrite(RDENB , vitesse) ;
      }


      

      if (Data == '2'){
        Serial.println("A droite");

        digitalWrite(RDIN3, HIGH) ;
        digitalWrite(RDIN4 , LOW) ;
      
        digitalWrite( RGIN2 , LOW) ;
        digitalWrite(RGIN1 , HIGH) ;
        
        analogWrite(RGENA , vitesseRotForte ) ;
        analogWrite(RDENB , vitesseRotFaible ) ;
      }

 

      if (Data == '4'){
        Serial.println("A gauche");

        digitalWrite(RDIN3, HIGH) ;
        digitalWrite(RDIN4 , LOW) ;
      
        digitalWrite( RGIN2 , LOW) ;
        digitalWrite(RGIN1 , HIGH) ;
        
        analogWrite(RGENA , vitesseRotFaible) ;
        analogWrite(RDENB , vitesseRotForte) ;
      }

      if (Data == '0'){
        Serial.println("Stop");
        digitalWrite(RGENA , LOW) ;
        digitalWrite(RDENB , LOW) ;
      }


      // moteur avant
      
      if (Data == 'A'){
        Serial.println("Train avant monte");

        digitalWrite(ArtFrontIN1, HIGH) ;
        digitalWrite(ArtFrontIN2 , LOW) ;
      
        digitalWrite(ArtFrontENA , HIGH) ;
      }

      if (Data == 'a'){
        Serial.println("Stop");
        digitalWrite(ArtFrontENA , LOW) ;
      }

      if (Data == 'B'){
        Serial.println("Train avant descend");

        digitalWrite(ArtFrontIN1, LOW) ;
        digitalWrite(ArtFrontIN2 , HIGH) ;
      
        digitalWrite(ArtFrontENA , HIGH) ;
      }

      if (Data == 'b'){
        Serial.println("Stop");
        digitalWrite(ArtFrontENA , LOW) ;
      }


      // Moteur centre
      
      if (Data == 'C'){
        Serial.println("Train central monte");

        digitalWrite(ArtMiddleIN1, LOW) ;
        digitalWrite(ArtMiddleIN2 , HIGH) ;
      
        digitalWrite(ArtMiddleENA , HIGH) ;
      }

      if (Data == 'c'){
        Serial.println("Stop");
        digitalWrite(ArtMiddleENA , LOW) ;
      }

      if (Data == 'D'){
        Serial.println("Train central descend");

        digitalWrite(ArtMiddleIN1, HIGH) ;
        digitalWrite(ArtMiddleIN2 , LOW) ;
      
        digitalWrite(ArtMiddleENA , HIGH) ;
      }

      
      if (Data == 'd'){
        Serial.println("Stop");
        digitalWrite(ArtMiddleENA , LOW) ;
      }


      // Moteur arrière
      
      if (Data == 'E'){
        Serial.println("Train arrière monte");

        digitalWrite(ArtBackIN3, HIGH) ;
        digitalWrite(ArtBackIN4 , LOW) ;
      
        digitalWrite(ArtBackENB , HIGH) ;
      }

      if (Data == 'e'){
        Serial.println("Stop");
        digitalWrite(ArtBackENB , LOW) ;
      }

      if (Data == 'F'){
        Serial.println("Train arrière descend");

        digitalWrite(ArtBackIN3, LOW) ;
        digitalWrite(ArtBackIN4 , HIGH) ;
      
        digitalWrite(ArtBackENB , HIGH) ;
      }

      if (Data == 'f'){
        Serial.println("Stop");
        digitalWrite(ArtBackENB , LOW) ;
      }


      //Tous les moteurs
      
      if (Data == 'H'){
        Serial.println("Robot monte");

        digitalWrite(ArtBackIN3, HIGH) ;
        digitalWrite(ArtBackIN4 , LOW) ;

        digitalWrite(ArtMiddleIN1, LOW) ;
        digitalWrite(ArtMiddleIN2 , HIGH) ;

        digitalWrite(ArtFrontIN1, HIGH) ;
        digitalWrite(ArtFrontIN2 , LOW) ;
      
        digitalWrite(ArtBackENB , HIGH) ;
        digitalWrite(ArtMiddleENA, HIGH) ;
        digitalWrite(ArtFrontENA , HIGH) ;
      }

      if (Data == 'h'){
        Serial.println("Stop");
       
        digitalWrite(ArtBackENB , LOW) ;
        digitalWrite(ArtMiddleENA, LOW) ;
        digitalWrite(ArtFrontENA , LOW) ;
      }

      if (Data == 'G'){
        Serial.println("Robot descend");

        digitalWrite(ArtBackIN3, LOW) ;
        digitalWrite(ArtBackIN4 , HIGH) ;

        digitalWrite(ArtMiddleIN1, HIGH) ;
        digitalWrite(ArtMiddleIN2 , LOW) ;

        digitalWrite(ArtFrontIN1, LOW) ;
        digitalWrite(ArtFrontIN2 , HIGH) ;
      
        digitalWrite(ArtBackENB , HIGH) ;
        digitalWrite(ArtMiddleENA, HIGH) ;
        digitalWrite(ArtFrontENA , HIGH) ;
      }

      if (Data == 'g'){
        Serial.println("Stop");
       
        digitalWrite(ArtBackENB , LOW) ;
        digitalWrite(ArtMiddleENA, LOW) ;
        digitalWrite(ArtFrontENA , LOW) ;
      }

    }
}

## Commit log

2021-12-01 Create Cahier des charges - remit
2021-12-05 Update Cahier des charges - remit
2021-12-05 Create Cahier des charges-Planning Roadmap.md
